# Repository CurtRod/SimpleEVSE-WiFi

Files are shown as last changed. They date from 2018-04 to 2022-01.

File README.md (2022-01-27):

# SimpleEVSE-WiFi

💬 [German version](https://www.evse-wifi.de/dokumentation/)

💾 [Latest Downloads, News and Changelogs (german)](https://www.evse-wifi.de/)

## Attention:
This file describes the structure of EVSE-WiFi in version 1.x.x and is only valid for the ESP8266. For the use of EVSE-WiFi 2.0 (based on ESP32) it is recommended to use the dedicated hardware 'EVSE-WiFi 2.0 Base'. You can find further information on www.evse-wifi.de. The EVSE-WiFi 2.0 Base Module can be bought [here](https://www.evse-wifi.de/produkt/evse-wifi-2-0-base/).

## Introduction

EVSE-WiFi brings WiFi functionality to your EVSE WB/DIN to control your Charging Station very easy. It uses an ESP8266 to communicate with the EVSE WB charging controller via ModBus (UART) and offers a web interface to control nearly everything. Optional there is a possibility to connect an impulse meter via S0 or a Modbus meter (RS485-TTL Adapter is required) and an RFID reader to detect valid RFID tags.

If you want to support this project, I would be very happy about a donation.



## Main Features

* WiFi functionality (as an access point or as a WiFi client)
* Activate and deactivate the Simple EVSE WB via a web interface, RFID tags, API or a button
* 'Always Active' mode - no manual activation necessary
* [HTTP-API](#http-api) to let other devices control EVSE-WiFi
* Setting the charging current via the web interface
* Displays the current charging power in kW (by impulses of a S0 or ModBus meter, optional)
* Displays the charged energy (kWh and km) and the cost of the charge (€)
* User management (RFID tags, optional)
* Log of the last charging processes with output of the charged energy quantity, charging time and costs of the charge (optionally which RFID tag the EVSE was enabled by and the user assigned to it)
* Rudimentary settings (WiFi settings, password for web interface, maximum charging current, etc.)
* Control over all EVSE WB/DIN modbus registers via web interface
* Output of all important parameters of the SimpleEVSE WB (Modbus)
* LED-Support (Pin D0)

## Buy the EVSE-WiFi-Module

If you do not have the time and desire to flash an ESP module and customize the libraries, you can also purchase the already prepared module in the shop with all wires and additional Hardware you need.

[EVSE-WiFi 2.0 Base Module](https://www.evse-wifi.de/produkt/evse-wifi-2-0-base/)

## Preview

Control the Current your EVSE communicates to the vehicle. This page also shows additional data like metered energy and the charging time.

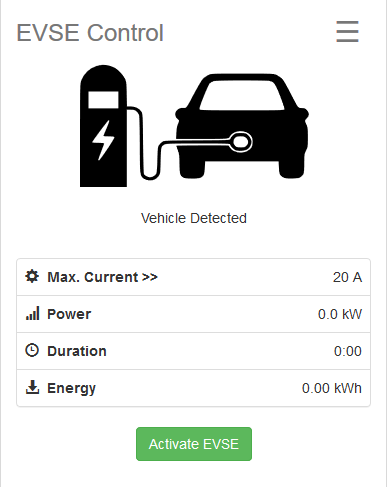
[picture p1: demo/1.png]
Showcase 1

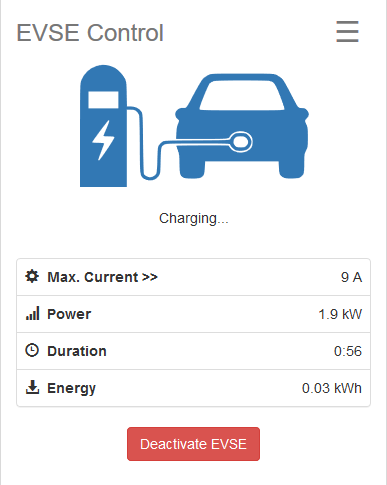
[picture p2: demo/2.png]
Showcase 2


The log page shows the last charging activities.

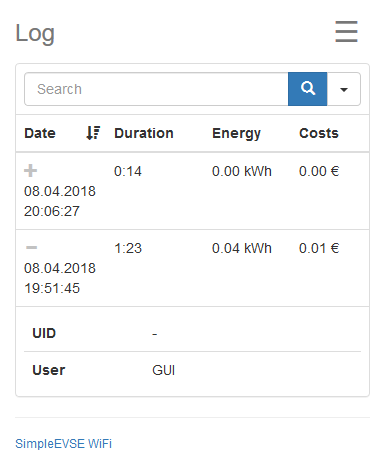
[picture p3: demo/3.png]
Showcase 3


At the users page you can define valid RFID tags that can unlock the EVSE.

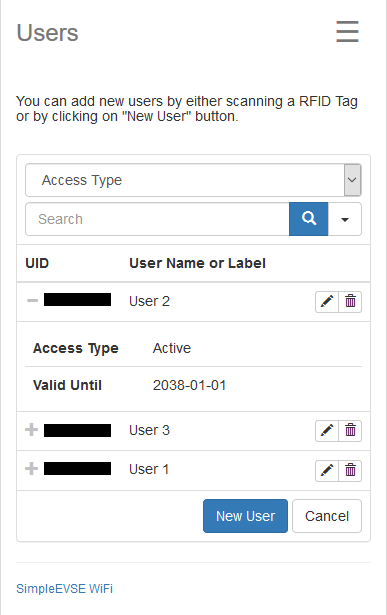
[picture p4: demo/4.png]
Showcase 4


## What You Will Need

### Attention:
This file describes the structure of EVSE-WiFi in version 1.x.x and is only valid for the ESP8266. For the use of EVSE-WiFi 2.0 (based on ESP32) it is recommended to use the dedicated hardware 'EVSE-WiFi 2.0 Base'. You can find further information on www.evse-wifi.de. The EVSE-WiFi 2.0 Base Module can be bought [here](https://www.evse-wifi.de/produkt/evse-wifi-2-0-base/).

### Hardware
* A complete Wallbox based on [EVSE Wallbox](https://www.evse-wifi.de/produkt/evse-wallbox-steuereinheit/) or [EVSE DIN](https://www.evse-wifi.de/produkt/evse-din-ladecontroller/) (min. Software revision 8 (2017-10-31) is needed - read the manual there for updating your EVSE software)
**Attention: revision 9 does not work, because there is a bug in the firmware (sold for a short time in 2018)**
* An ESP8266 module or a development board like **WeMos D1 mini** or **NodeMcu 1.0**
* (optional) An electricity meter with S0 or RS485/Modbus interface. (At this time only SDM120 and SDM630 are supported for use with Modbus)
* (optional) A [RFID Module](https://www.evse-wifi.de/produkt/evse-wifi-rfid-reader-modul/) (PN532 and Wiegand based RFID reader modules are not supported at this time)
* (optional) n quantity of [Mifare Classic 1KB](https://www.evse-wifi.de/produkt/evse-wifi-rfid-karte/) (recommended due to available code base) PICCs (RFID Tags) equivalent to User Number

#### Wiring (WeMos D1 mini/ NodeMcu)
SimpleEVSE-WiFi supports not only the control of the EVSE WB but also the use of a simple button or an RC522 RFID card reader to activate the charging process. With an optional electricity meter, the power requirements of the individual charging processes can be output.

##### Mandatory
This wiring is mandatory and absolutely needed to run SimpleEVSE-WiFi

ESP8266-Pin | ESP8266-GPIO | EVSE WB
----------- | ----------- | -----------
D1 | GPIO5 | TX
D2 | GPIO4 | RX
GND |  | GND

##### Button (optional)
ESP8266-Pin | ESP8266-GPIO | Button
----------- | ----------- | -----------
D4 | GPIO2 | Pin 1
GND | | Pin 2

##### S0 Electicity Meter (optional)*
ESP8266-Pin | ESP8266-GPIO | electricity meter
----------- | ----------- | -----------
D3 | GPIO0 | S0+
GND | | S0-

##### LED (optional)
ESP8266-Pin | ESP8266-GPIO | LED
----------- | ----------- | -----------
D0 | GPIO16 | Anode (+)
GND | | Kathode (-)

##### Modbus Electicity Meter (optional)**
TTL->RS485 | ESP8266-Pin
----------- | -----------
RX | RX 
TX | TX 
VCC | 5V
GND | GND

TTL->RS485 | Modbus Meter 
----------- | -----------
A+ | A
B- | B

##### RC522 RFID-Reader (optional)
ESP8266-Pin | ESP8266-GPIO | RC522
----------- | ----------- | -----------
D5 | GPIO14 | SCK
D6 | GPIO12 | MISO
D7 | GPIO13 | MOSI
D8 | GPIO15 | SDA
GND |  | GND
3.3V |  | 3.3V

Be sure to use a suitable power supply for ESP. At least 500mA is recommended!

\*When you use an electricity meter with S0 interface be sure the S0 interface switches to GND, don't use 3.3V or 5V!

\*\*To use a Modbus electricity meter via RS485, you need a extra piece of hardware to translate UART to RS485. In this project a PCB like [this](https://www.evse-wifi.de/produkt/evse-wifi-ttl-rs485-converter/) is required. Set your meter to baud rate 9600 and slave ID to "002". Until now only SDM120 and SDM630 Modbus meters are supported! If you have another one you can use it with the S0 interface.

#### Preparation of EVSE Wallbox
To use EVSE-WiFi, the modbus functionallity of EVSE WB/DIN is needed! By default, modbus functionality is disabled. To activate it, pull AN input of the EVSE board to GND while booting for at least 5 times within 3 seconds. Modbus register 2001 will be set to 1 (Modbus is active). Attention: That change will not be saved! To save the settings, you have to give a R/W operation at a register >=2000. The easiest way to do this is to activate and deactivate EVSE through the WebUI in the "EVSE Control" page.

### Software

#### Attention:
This file describes the structure of EVSE-WiFi in version 1.x.x and is only valid for the ESP8266. For the use of EVSE-WiFi 2.0 (based on ESP32) it is recommended to use the dedicated hardware 'EVSE-WiFi 2.0 Base'. You can find further information on www.evse-wifi.de. The EVSE-WiFi 2.0 Base Module can be bought [here](https://www.evse-wifi.de/produkt/evse-wifi-2-0-base/).

**Attention:** make sure that the EVSE WB/DIN is not connected to the ESP during the flash process via USB. It could cause overheating of the ESP.

#### Use Compiled Binaries
Compiled firmware binary and flasher tool for Windows PCs are available in on www.evse-wifi.de. On Windows you can use **"flash.bat"**, it will ask you which COM port that ESP is connected and then flashes it. You can use any flashing tool and do the flashing manually if you don't want to use the flash.bat.

[Download Firmware](https://www.evse-wifi.de/download/)

#### Building From Source
Please install Arduino IDE if you didn't already, then add ESP8266 Core on top of it. Additional Library download links are listed below:

* [Arduino IDE](http://www.arduino.cc) - The development IDE
* [ESP8266 Core for Arduino IDE](https://github.com/esp8266/Arduino) - ESP8266 Core
* [ESPAsyncWebServer](https://github.com/me-no-dev/ESPAsyncWebServer) - Asyncrone Web Server with WebSocket Plug-in
* [ESPAsyncTCP](https://github.com/me-no-dev/ESPAsyncTCP) - Mandatory for ESPAsyncWebServer
* [ESPAsyncUDP](https://github.com/me-no-dev/ESPAsyncUDP) - Mandatory for ESPAsyncWebServer
* [ModbusMaster](https://github.com/CurtRod/ModbusMaster) - ModbusMaster Library for communicating with EVSE (**NOTE: Use my Fork of ModbusMaster! Otherwise the wdt reset will be triggered in case of timeout error**)
* [SoftwareSerial](https://github.com/plerup/espsoftwareserial) SoftwareSerial to communicate with EVSE
* [MFRC522](https://github.com/miguelbalboa/rfid) - MFRC522 RFID Hardware Library for Arduino IDE
* [ArduinoJson](https://github.com/bblanchon/ArduinoJson) - JSON Library for Arduino IDE
* [NTPClientLib](https://github.com/gmag11/NtpClient/) - NTP Client Library for Arduino IDE
* [TimeLib](https://github.com/PaulStoffregen/Time) - Mandatory for NTP Client Library
* [ESP8266Ping](https://github.com/dancol90/ESP8266Ping) - Needed for checking online Status

You also need to upload web files to your ESP with ESP8266FS Uploader.

* [ESP8266FS Uploader](https://github.com/esp8266/arduino-esp8266fs-plugin) - Arduino ESP8266 filesystem uploader

Unlisted libraries are part of [ESP8266](https://github.com/esp8266/Arduino) Core for Arduino IDE, so you don't need to download them, but check that at least you have v2.4.0 or above installed.

## First boot
When SimpleEVSE-WiFi starts for the first time it sets up a WiFi access point called 'evse-wifi'. You can connect without a password. To connect, open http://192.168.4.1 in your browser. The initial password is 'adminadmin'. You should first check the Settings to bring the ESP in Client mode and connect it to your local WiFi network. The ESP will be restarted afterwards. If it doesn't restart, press the 'RST' button once. Sometimes the ESP must first be manually reset (this only has to happen after flashing a new firmware).

## Support this Project
The development of SimpleEVSE-WiFi is very time consuming. If you want to support this project, I would be very happy about a [donation](https://www.paypal.com/pools/c/85c7xRbeay).

## HTTP API
Since version 0.2.0 there is an HTTP API implemented to let other devices control your EVSE-WiFi. The API gives you the following possibilities of setting and fetching information.

### getParameters()
gives you the following information of the EVSE WB in json:

Parameter | Description
--------- | -----------
vehicleState | Vehicle state (ready / detected / charging)
evseState | EVSE State (active/not active)
maxCurrent | Maximum Current depending on PP-limit and 
actualCurrent | Actual configured current in A (e.g. 20A)
actualPower | actual power consumption (when S0 meter is used)
duration | charging duration in milliseconds
alwaysActive | Always Active Mode enabled (true/false)
lastActionUser | The user name of the user who performed the last action (activate/deactivate)
lastActionUID | The UID of the user who performed the last action (activate/deactivate)
energy | charged energy of the current charging process in kWh
mileage | charged energy in km
meterReading | actual meter reading in kWh
currentP1 | actual current in A (phase 1)
currentP2 | actual current in A (phase 2)
currentP3 | actual current in A (phase 3)
useMeter | energy meter is configured in EVSE-WiFi (true/false)

#### Example
`GET http://192.168.4.1/getParameters`

> returns JSON like this:

```json
{
  "type": "parameters",
  "list": [{
    "vehicleState": 2,
    "evseState": false,
    "maxCurrent": 32,
    "actualCurrent": 32,
    "actualPower": 5.79,
    "duration": 1821561,
    "alwaysActive": false,
    "lastActionUser": "GUI",
    "lastActionUID": "GUI",
    "energy": 9.52,
    "mileage": 82.3,
    "meterReading": 54.35,
    "currentP1": 8.54,
    "currentP2": 8.54,
    "currentP3": 8.54,
    "useMeter": true
  }]
}
```

### getLog()
returns the following information about the last log entries

Parameter | Description
--------- | -----------
uid | The UID of the RFID tag that was used to activate EVSE
username | The username belongs to the UID
timestamp | Timestamp in seconds since Jan 01 1970 (Unix timestamp)
duration | Duration of the charging process in milliseconds
energy | Charged energy of the charging process in kWh
price | Defined price per kWh in cent

#### Example
`GET http://192.168.4.1/getLog`

> returns JSON like this:

```json
{
  "type": "latestlog",
  "list": [{
    "uid": "ABCD1234",
    "username": "GUI",
    "timestamp": 1523295915,
    "duration": 7504266,
    "energy": 10.32,
    "price": 21
  }, {
    "uid": "-",
    "username": "GUI",
    "timestamp": 1523568920,
    "duration": 1152251,
    "energy": 2.17,
    "price": 23
  }]
}
```

### setCurrent()
using setCurrent() will set the current to the given value (e.g. 18A)

Parameter | Description
--------- | -----------
current | Current to set in EVSE WiFi

#### Example

`GET http://192.168.4.1/setCurrent?current=8`

> Sets the charging current  to 8A and returns

```text
S0_set current to 8A
```
In cases of Error, the answer would be

Answer | Description
--------- | -----------
E0_could not set current - internal error | Internal error occured (unspecified)
E1_could not set current - give a value between *x* and *y*  | Wrong value was given
E2_could not set current - wrong parameter | Wrong parameter was given

### setStatus()
will activate/deactivate EVSE WB

Parameter | Description
--------- | -----------
active | can be true (activate EVSE) or false (deactivate EVSE)

#### Example

`GET http://192.168.4.1/setStatus?active=true`

> Activates EVSE and returns

```text
S0_EVSE successfully activated
```
In cases of Error, the answer would be

Answer | Description
--------- | -----------
E0_could not activate EVSE - internal error | Internal error occured (unspecified)
E0_could not deactivate EVSE - internal error | Internal error occured (unspecified)
E1_could not process - give a valid value (true/false) | Wrong value was given
E2_could not process - wrong parameter | Wrong parameter was given
E3_could not activate EVSE - EVSE already activated! | EVSE is already in state "active"
E3_could not deactivate EVSE - EVSE already deactivated! | EVSE is already in state "deactive"

### doReboot()
reboots EVSE-WiFi via ESP.restart()

Parameter | Description
--------- | -----------
reboot | must be true to reboot EVSE-WiFi

#### Example

`GET http://192.168.4.1/doReboot?reboot=true`

> Returns 

```text
S0_EVSE-WiFi is going to reboot now...
```
In cases of Error, the answer would be

Answer | Description
--------- | -----------
E1_could not do reboot - wrong value | Wrong value was given
E2_could not do reboot - wrong parameter | Wrong parameter was given

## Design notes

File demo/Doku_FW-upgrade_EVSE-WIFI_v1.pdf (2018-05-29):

Dokumentation für das Aufspielen einer neuen „EVSE-WIFI“ Firmware auf einen ESP8266 – Stand 24.05.2018
Anleitung für Windows-PC
1. Aufruf der „EVSE-WIFI“-Webseite im Browser: Adresse http://192.168.xxx.yyy (IP-Adresse entsprechend aktuellem Modus (client- oder AP) wähen)
2. Login mit PW und zur setting-Seite navigieren

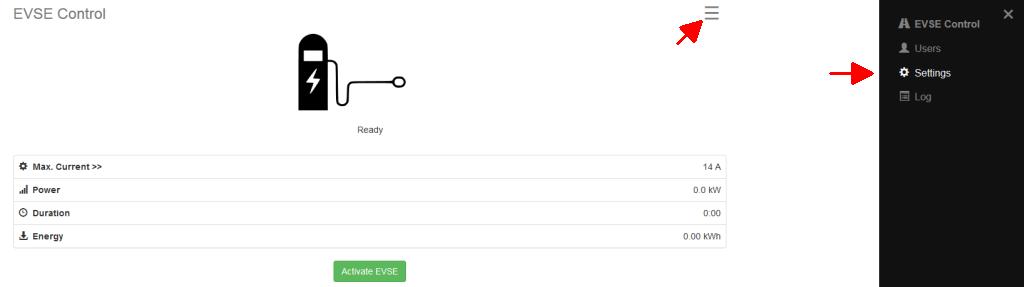
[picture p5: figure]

3. An das untere Seitenende scrollen, nun Daten (a) und Settings (b) in jeweils eine Datei sichern
Anschließend dem link „latest version“ (c) folgen

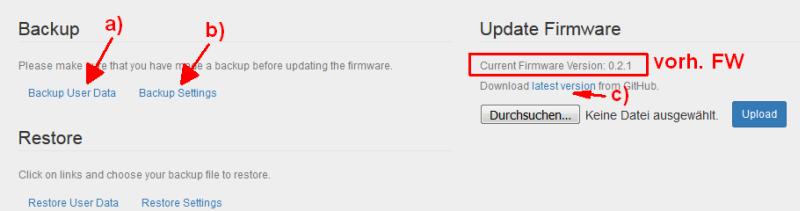
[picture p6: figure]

4. auf Github in das aktuelle EVSE-WIFI-Versionsverzeichnis (hier 0.2.2) navigieren und die Datei Source code.zip in ein PC-Verzeichnis Deiner Wahl downloaden (meist in den Download-Ordner)

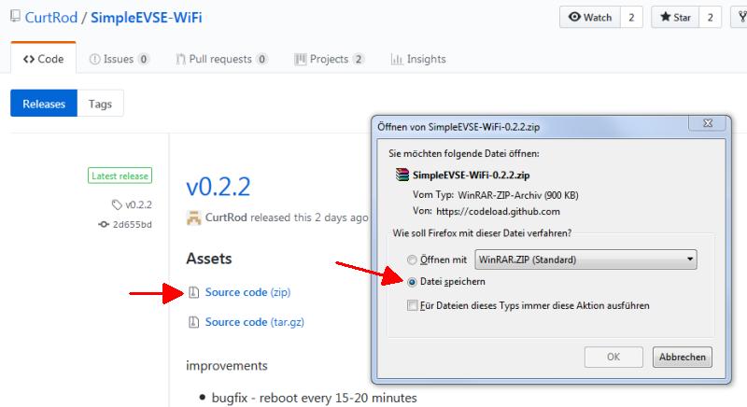
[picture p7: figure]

5. zip-Datei auf dem PC entpacken => In etwa folgender Inhalt muss erscheinen.

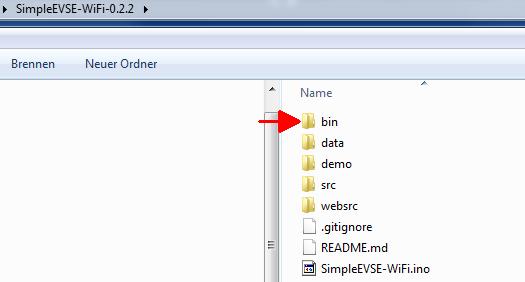
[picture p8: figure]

6. Nun mit Explorer in den Ordner bin u. ggf. Unterordner (hier latest) wechseln und das Vorhandensein der Datei built.bin prüfen

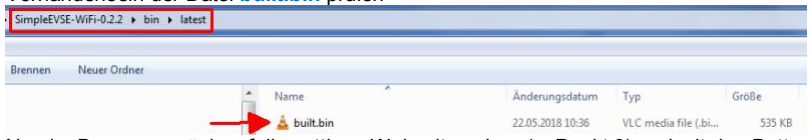
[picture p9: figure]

7. Nun im Browser zurück auf die settings-Webseite gehen (s. Punkt 3) und mit den Button „Durchsuchen…“ (d) zu lokal gespeicherten built.bin-Datei navigieren,
nach Doppelclick auf built.bin (oder Öffnen) ist die neue Firmware für den upload bereit (e), nun den Upload-button starten (f)

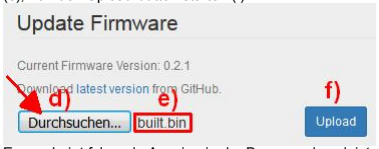
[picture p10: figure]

8. Es erscheint folgende Anzeige in der Browseradressleiste:
9. Nach ca. 30s warten, bitte die IP von „EVSE-WIFI“ aufrufen (s. Punkt 1) und wieder zur setting-Seite navigieren (s. Punkt 2) => dort die neue FW-Version prüfen

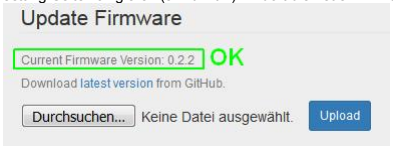
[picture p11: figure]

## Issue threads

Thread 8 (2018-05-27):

Save & Reboot doesn't work

Leftaf, 2018-05-27:
In the build 0.2.2 the [Save & Reboot] button is complain the the default PW is shorter than 8 Char, but if I change it and also other settings it doesn't save them to the config file.

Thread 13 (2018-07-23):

SimpleESVE - Firmware Version

njordan77, 2018-07-23:
Sorry to post this in issues as this is no issue at all, but no other chance seen to get in touch with the developer. Is there any chance/hidden website that would provide firmware version of the controller board. I bought it recently but would like to see if its rather up to date or better should buy a Pickit3/4....Thanks Norbert

njordan77, 2018-07-23:
ah, sorry - just did dig deeper - there is a device status part where one register names the firmware version. Says 9, which seems to be the latest one on the internet dated 180425. Regards

Closed 2018-07-23.

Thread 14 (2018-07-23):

Button yes/no?

njordan77, 2018-07-23:
One short question before i add this element. What if i do not consider a button? will it start when plugged in or it waits until the GUI activates the controller?

What if i use the button and activate and somebody else presses the button again....will it disable again? if this is the case its a little dangerous if i leave the car in public and e.g. kids playing next to this nice box and turn it off "accidentially"....

Thanks a lot for clarification, Norbert

CurtRod, 2018-07-23:
Hi Norbert,

Thank you for your Message! SimpleEVSE-WiFi waits to activate until the button is pushed, reading a RFID tag or activating via WebUI.
Deactivating works the same. So yes, it could be dangerous, when kids playing next to the Box! ;-)
A possible solution could be a flag in the Settings like "allow deactivating via Button". Maybe this will be delivered with the next release.

You can follow the discussions about SimpleEVSE-WiFi also on goingelectric.de (german):
https://www.goingelectric.de/forum/ladeequipment/simpleevse-wb-mit-wlan-t31260.html

Curt

njordan77, 2018-07-25:
One question regarding the hardware part of this button.
Should the button bring GND to the configured GPIO pin? should this be done simply via connecting to GND....or should this be done via PULL-UP Resistor in combination with the button in order to have stable 3,3V when not pressed at the pin.

How about debounce, is there something implemented in Software or its expected to happen in Hardware? Regards Norbert

CurtRod, 2018-07-26:
Hi Norbert,
as described in README.MD the button should bring the GPIO to GND. The ESP8266 Module has internal Pull-Up resistors, which are used here. There is no hardware Pull-Up necessary.
Debounce is already prevented in Software.

Curt

Macrisu, 2019-07-23:
The original design asks for an auto-reset button.
I used that button with ESVE-Wifi and it works only if the connection is closed (I keep pressing the button).
It can be made to work with that button, or do I need to buy a classic on/off button?

Closed 2018-07-23.

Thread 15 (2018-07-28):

No authentication possible on Safari MacOS and iOS

michel72, 2018-07-28:
It's not possible to authenticate on iOS and MacOS because apple devices do not allow basic auth without https.

In short, it's not possible to use the webUI from and Apple IOS device at all and It's not possible to use the webUI on a Apple Macbook using the Safari webbrowser. It does work on a Macbook when using Chrome or Firefox.

njordan77, 2018-08-01:
can confirm this....on Win10 everything connects perfect to APmode....but iphone does show the login mask but from there it does not continue with correct password into the main GUI.....is there a way to fix this?

njordan77, 2018-08-14:
Any progress here, or solution that could fix the issue?

CurtRod, 2018-08-14:
Sorry for late response. I will try to find a solution asap.

Leftaf, 2018-08-28:
I found following https://github.com/Links2004/arduinoWebSockets

and Issue https://github.com/Links2004/arduinoWebSockets/issues/25

may this help to improve security to iOS

njordan77, 2018-11-11:
Hi, any update? Tried recently the latest version + hoped naively that IOS12 could have fixed it - but no success. Still not able to connect in AP Mode from my Iphone. Connecting with my PC (Win+Firefox) is no problem at all. Regards Norbert

CurtRod, 2018-12-25:
I suspect the error in the JS part of the web interface. Unfortunately, I do not have a Mac to hit the debugger in Safari. So at the moment I can not analyze what exactly the problem is. Does anyone have the opportunity to do this? That would be great.

njordan77, 2018-12-25:
hi, i would love to support - but the only thing i have in hand is an iphone 6s - if that may help. Thanks for the support!

michel72, 2018-12-26:
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

michel72, 2018-12-26:
Safari does not allow basic auth for websockets.

https://serverfault.com/questions/910702/apache2-safari-exclude-basic-authentication-for-websockets

michel72, 2018-12-27:
@CurtRod , if you need any help testing, I have an iMac, macbook, iPhone and iPad available.

CurtRod, 2018-12-27:
@michel72 , thank you. I wondered, because i've seen some other projects using websockets with basic auth and there are no problems with safari. I have only an iPhone 7 for testing here but there is no way to debug with that.
**good news for all Apple users:**
In the next release will be an option to deactivate the basic auth, however this should only be a work around and not a preferred solution.

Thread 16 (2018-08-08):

Feature request: Options to autoactivate the charging station on power on and to prevent deactivation after charging

FrenkK, 2018-08-08:
Hello :) First of all, thank you for this very useful project, it fills a real need!
I'm using it on my home charging station for three primary purposes: for monitoring, to be able to dynamically adjust charging amperage to prevent my main fuses from blowing out (using the setCurrent API) and for the power measurement capability. Configuration: a S0 energy meter, no RFID, no button.
I have two issues:
1. Currently, the controller will turn off the SimpleEVSE after each charge (writing 8192 to register 2005 at the start). This is a problem on my Ampera for two reasons:
  - The car stops indicating a full charge and I can't verify a proper charge without turning the car back on. We have very unstable power, so charging problems happen more often than you would think.
  - Ampera should be always connected to a charger in extremely warm or freezing weather so the system can protect the battery by heating or cooling it (AFAIK, this goes for other e-cars as well).
2. There are several of us using this station and everybody expects to just plug in the cable and leave. If a  short blackout occurs (and it does quite frequently), the station restarts, but does not reactivate, so they have to first check if it is charging and then activate it, if it doesn't, This already caused some failed charges.

I think these issues will probably be bothering other people as well, so it would be nice to have two simple checkboxes in config: "Do not deactivate after finished charge" and "Automatically activate the station on power on".

Leftaf, 2018-08-10:
Hi Frenkk,

For the handling with the Cars there is a possibility to improve. If you have a cable with Plug normally PP is fix with GND connected e.g. 680 ohm to indicate 16A . If you modify the Plug to that the PP to GND can be opened. The Car would normally get reactivated and will try to charge again.

To avoid blackouts on the esp6288 side you may use the latest version with battery support. [WEMOS V2.0.0](https://wiki.wemos.cc/products:d1:d1_mini_pro)

CurtRod, 2018-08-28:
@FrenkK Thank you for that feature request. I have already considered that this may be a possible scenario. Via hardware it will probably not be possible to stop setting register 2005. Each time the ESP is restarted, EVSE WB is automatically deactivated.
The problem with the implementation right now is that it's not so easy to notice that a charge has been started. This would require the EVSE WB to be polled for every few seconds. But it's not impossible. I'll include that in the backlog as a new feature. At the moment, however, there is still a stability issue with the HTTP API, which should be fixed before. I keep that in focus.

FrenkK, 2018-09-02:
Thank you for keeping this in mind. I actually bodged up a quick fix to prevent the autodeactivate on startup and recompiled, but it is not even close to a proper solution.

ronmichel, 2019-10-06:
@FrenkK Could you be so kind and share your quick fix to prevent the autodeactivate on startup? Thanks so much!

FrenkK, 2019-10-08:
@ronmichel What I did was to strip all the code I don't need from the 2.6 version and then add the logic that keeps it on. There is also a tweak to the JSON reporting of current, I removed the unnecessary nesting in the result that was messing with my Home Assistant setup.
You are free to use the slimmed down code attached, but it's a quick and dirty job with some functions (like Modbus meter support) removed.
[SimpleEVSE-WiFi.zip](https://github.com/CurtRod/SimpleEVSE-WiFi/files/3700710/SimpleEVSE-WiFi.zip)

ronmichel, 2019-10-08:
Thanks! I also plan to use it with HA so it suits just fine!

CurtRod, 2019-12-03:
resolved with version 0.3.0

Closed 2019-12-03.

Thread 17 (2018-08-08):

Contribution: STL files for a simple 3D-printed DIN-rail enclosure for the WeMOS D1 mini

FrenkK, 2018-08-08:
I made a simple DIN-rail enclosure design for the WeMOS D1 mini.
It's made of two halves that are screwed together using recessed-head wood screws. There is (just) enough space to install a simple 5V power supply cannibalised from a phone charger. The antenna is exposed for best possible WiFi reception.
Build:
1. For safety, print using fire retardant plastic.
2. Connect all parts and use a drop of superglue to hold them in place in the enclosure.
3. Screw the enclosure together using 4x 3,6x16 mm wood screws with a recessed head.

See the picture for the final look (rightmost module).
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
[STLs.zip](https://github.com/CurtRod/SimpleEVSE-WiFi/files/2269021/STLs.zip)

Macrisu, 2019-08-15:
Thank you for the 3D STL files.
I see that you also put a LED and button on the DIN case, very nice.
You use the button to activate the charge?

I've tried this, but it does not seem to work for me. I have an auto-reset button that works only if I keep the button pressed manually.
**Your button is on/off or auto-reset?**

Thank you

FrenkK, 2019-08-16:
> You use the button to activate the charge?
No, this is a fallback in case the SimpleEVSE-WiFi fails. It is a momentary NO switch corrected directly to the control input on the Simple EVSE Wallbox. If there is ever a big problem with the Simple EVSE Wifi, I can just turn off its power and use the wallbox on it's own.

Macrisu, 2019-08-16:
Do you have the original cad files for STL?
I want to make the WeMOS D1 mini support smaller.

FrenkK, 2019-08-17:
Sure, I added them to the original post.

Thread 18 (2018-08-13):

switch to STA mode is failing only emergency AP Mode get's activate.

Leftaf, 2018-08-13:
It looks like that there is an issue to switch from AP mode to STA after once AP has been Setup successful.

Trying to go into STA mode always the WEMOS start in fallbacktoAPMode();
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
as this function is only called in the Setup(); sequence there must be an issue with loading the config.json
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

Does any body else have this behavior?

in depend of this behavior the [debug] activation is unfortunately after the relevant error messages :-( so the code should be move upwards and the first messages should be always shown.
`````
bool ICACHE_FLASH_ATTR loadConfiguration() {
  File configFile = SPIFFS.open("/config.json", "r");
  if (!configFile) {
    Serial.println(F("[ WARN ] Failed to open config file"));
    return false;
  }
  size_t size = configFile.size();
  std::unique_ptr<char[]> buf(new char[size]);
  configFile.readBytes(buf.get(), size);
  DynamicJsonBuffer jsonBuffer14;
  JsonObject& json = jsonBuffer14.parseObject(buf.get());

  if (!json.success()) {
    Serial.println(F("[ WARN ] Failed to parse config file"));
    return false;
  }
  if (json.containsKey("debug")){
    debug = json["debug"];
  }
  if(debug){
    Serial.println("Debug Mode: ON!");
    Serial.println(F("[ INFO ] Config file found"));
    json.prettyPrintTo(Serial);
    Serial.println();
  }
  else{
    Serial.println("Debug Mode: OFF!");
  }
```

CurtRod, 2018-08-14:
Thank you for reporting this issue. I will have a look at this in the next days!

CurtRod, 2018-08-28:
okay. I changed the lines a bit diffent, but now there would be an error message on Serial, when no config file is found. Thank you for your help.

Closed 2018-08-28.

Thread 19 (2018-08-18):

Dangerous: EVSE defaults to 32A after reboot!

michel72, 2018-08-18:
I have noticed the SimpleEVSE-Wifi defaults to 32A after a reboot even though I have set the MAX CURRENT in settings to 20A. THe webUI shows 32A and that settings is actually active.
This leads to a potential dangerous situation as the car will pull 32A if activated after a power failure.

I have set the ESP to
- Wifi client
- Meter hardware to SO
- NO RFID
- MAX Current: 20A
- NO button
- NTP server set to pool.ntp.org
- time zone set to GMT+1 Brussels

EVSE Registers
1000: Configured Current	16
1001: Actual Current	16
1002: Vehicle Status	3
1003: PP-Limit	20
1004: Turn off bit	0
1005: Firmware Version	9
1006: EVSE Status	2
2000: Current after boot	32
2001: Modbus Status	1
2002: Min. Current Value	5
2003: Analog Input Config	1
2004: Amps after boot (evse-button)	0
2005: Register 2005	8192
2006: Current Sharing Mode	0
2007: PP-Detection	0

Current after boot is set to 32A, but I have no clue as how to set that to 20A.

Leftaf, 2018-08-23:
In depended of this situation. My understanding is that the resistance PP-PE will overrule physical the limit

If you have bluetooth available try the APP from the developer to change the register.
http://evracing.cz/evse/evse-wallbox/app_20171118.apk

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

CurtRod, 2018-08-23:
Hi michel72,

sorry for the late response. You don't need the HC06 BT Interface to do that. In the WebUI of SimpleEVSE-WiFi you can click the 'pencil' on top of the table 'EVSE Registers' in Settings page (see attached screenshots). Click that and than you can change register 2000 (Current after boot) to 20.
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

Curt

michel72, 2018-08-23:
Ahh thanks. This was obviously not a bug :)

Closed 2018-08-23.

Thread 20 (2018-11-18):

Reconnect or connect if use timer

autodiag, 2018-11-18:
I have a bit of a problem with using in a while when I have a timer setting (to run at a low tariff) so the charging is not started, is the problem of the system itself or is the problem elsewhere?
if it's a system problem, would it be good to run timers and run automatically at the set time?

the kind of problem is that if I press the button on the car connector, I will not be charged as I have any other chargers and I have to re-enter the phone (or the button)
I have a 680R resistor (for 20A limit) PP to GND ..
Is this involved well or do I have to engage PPs on the car?
it was not quite clear to me from the description

Martin

autodiag, 2018-11-18:
i use J1772 and car is Fiat 500e

CurtRod, 2018-12-25:
Hey Martin,

sorry for the late reply, I was a little longer on vacation. :)
The 680R resistor in the cable should not be a problem.
Do I understand correctly that you are using the timer function of your vehicle? There will be a timer function directly in SimpleEVSE-WiFi with one of the next releases. Maybe that would be the easier way. Is SimpleEVSE-WiFi in the status 'activated' when the vehicle requests the charging depending on the vehicle's pre-setting?

Curt

autodiag, 2019-01-17:
when I have a timer set in my car due to a cheap night's charge, the EVSE does not charge the car, it will not start ... just start if the timer is off, I load the charger and charge ... but if I pull out the charger and reinsertion or if the electrified site will drop out of the car and it will not restart again .. it will be possible to run the manual manually via the web interface ... it might not be wrong to choose whether to plug in the car or to start up manually, that would solve the problem, I think along with the timer to help the charger, not the car

Matin

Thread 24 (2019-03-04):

Feature Request: stop charging when power/current below defined value (stop charging at 80%)

badsoden, 2019-03-04:
It would be nice if one could set a treshhold where the charging will be halted when power/current gets below defined value. The idea is to set that value where the SoC is about 80%. Not all cars support charging stop at a certain SoC value and this way the EVSE could manage this. It increases lifetime of the battery and allow full recuperation right after start driving. E.g. Renault ZOE does not have an option to charge at 80% and the battery must be well below ca. 90% to have full recuperation. So charging at 80% is good for battery and lowers your average consumption.
For each car the owner shuld first estimate/assess the actual current at 80% SoC and then set the treshold accordingly.

FrenkK, 2019-03-04:
AFAIK, the car does not send a feedback about state of charge to the EVSE with SAE J1772 signaling protocol, so this is not really feasible without some additional hardware, at least not accurately.
The recuperation is a valid argument, but that aside, I question if it makes sense to do this. Car batteries are used in a much narrower voltage window than consumer batteries you can find e.g. in phones. In my Opel Ampera, for example, only 10 out of 16 kWh capacity is used and cell voltage never goes above 4 V (as opposed to 4,2 V in consumer batteries). Decreasing the charge window still further will probably not make much difference and you should already get at least some 5000 cycles of life. It may be a factor with some cars, depending on their use of the battery, although for sure not a big one.

badsoden, 2019-03-04:
I though so, that there is no feedback about SoC. That's why I suggested to use the charging curve. The car reduces charging current at around 70 to 80% with most cares and I though I use that to estimate SoC. I thought in its most simple form one would just be able to set minimum current and when it goes below charging stops. It most have a short waiting time before it kicks in to ensure the car takes maximum power (above the treshhold). E.g. logic would be: after start charging wait one minute and then if current below xyz then stop.
That 80% is better for the battery I derived from Tesla that normally stops at 80% unless you explicitly set the flag to charge 100%. That some manufacturers put more capacity in the car than actually seen is true. In my ZOE I though it is another 2 or 4 KWH on top of the specified 22 KW.

Recuperation is especially valid if one lives uphill. If you charge till 100% and drive down after charging then that last 5% to 10% of charge is basically wasted because one can't recuperate.

FrenkK, 2019-03-04:
Yes, the charging curve approach should work, if you have an energy meter connected. It is not trivial, though, because it must take into account the set current that can change with dynamic load shedding, for instance.

badsoden, 2019-03-04:
That is very true, one probably has to average out the (s0) measured values over some minutes and then shut off charging. If one loads 79 or 81% is not very critical anyway so a few minutes earler or later is not important. Some basic rolling robin algorithm should do the job.

Macrisu, 2019-07-20:
for LEaf, It can be done with an Android APP.
https://play.google.com/store/apps/details?id=com.chk.lcc&hl=en

premultiply, 2019-11-22:
The way to estimate the SOC from the charging power does not work reliable.
Charging Power measured on EVSE side depends on many factors like battery temperature, pilot signal, battery voltage, preconditioning state, battery heating, ...

It would end in may problems and failures.

Apart from that it is kind of useless as the BMS keeps track of the battery health itself and 100% displayed SOC for user does not mean the battery cells are fully charged on most types of cars, especially ZOE.

badsoden, 2019-11-22:
I know the ZOE doesn't report real SoC. My main issue is, that recuperation is more or less disabled when you start driving with a 100% battery. In fact I don't mind when the battery is loaded somewhere between 75 and 95 %. I just want to sty away from the 100%. I also not so convinced that Renault's BMS is very accurate with loading. Renault is quite buggy with all of their SW hence why would their BMS be an exemption. So, if unreliable means one day (e.g. when cold) it would stop at 75% and another day in summer it would charge to 90% I can live with that, recuperation will work right from start and the battery will definitely not suffer from that. Actual current measurements can come from S0 sensor or RS485 bus from separate power meter.
Is it worth it to make this effort on the EVSE for a ZOE only? Not sure obviously and not up to me to judge or answer. ZOE is a popular car but if it is the only EV with such limited charging control then I understand it's low on the priority list. I really don't know how many cars do not allow to set the end of charging at a certain level of SoC. The facelifted ZOE (2019) doesn't allow it either. Their App to track charging or SoC is not working any more which I found all quite disappointing. One could overcome it by setting a timer but this is quite cumbersome as one can set a clock but not a timer.  The environmental gain of a EV does depend on the final life span of the battery and ZOE is not really making an effort here it seems.

premultiply, 2019-11-23:
Why dont you have a look for OpenWB? All these kind of advanced features are included there.

But this project here should hopefully stay smart, small and clean.

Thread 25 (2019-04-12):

MQTT for EVSE-WIFI

roesl, 2019-04-12:
Is it possible to add MQTT feature to Control the EVSA wit MQTT commands ?

Georg

s0170071, 2019-09-16:
+1 from me.
I do already have the mains power readings and solar power readings in my OpenHab installation.
I would like either
a) communicate these power readings to EVSE so it can use it for solar charging
b) control power output of EVSE myself (based on my readings)
MQTT style is very much appreachiated.

neographikal, 2020-02-16:
+1

This would make it much more versatile!

alx2k, 2020-02-25:
@neographikal, It would be much more versatile, but it is not needed.

I have "home assistant" at home, and a wemosEM power meter (also on github). When my home consumption changes in 1 Amp, home assistant sends a http request to the charger using "http://192.168.4.1/setCurrent?current=XXXX". It works flawlessly.

@s0170071, If you want, I can send you my home assistant configuration, maybe it is similar in Openhab.

neographikal, 2020-02-25:
I can get it to work, but MQTT is much more versatile, reliable and almost everything I use is connected through MQTT. Especially when it's a ESP32/8266 (Tasmota/esphomelib), for some stuff I even wrapped the existing API for MQTT with Nodered.

Thanks for the suggestion but this still would be important to me :)

spoeh-man, 2020-05-11:
+1 for me is also better with mqtt for iobroker

njordan77, 2020-05-13:
i would also love to see your great project compatible with MQTT (pubsubclient, rather easy to handle)

kolaCZek, 2020-06-24:
+1 Do want!!!

krispek, 2020-07-07:
+1 for me. The HA-solution works, but MQTT would make it even better. :)

captain186, 2020-10-15:
> If you want, I can send you my home assistant configuration, maybe it is similar in Openhab.

Hi, I'm intrested in using evse-with home assistant. Could you send me your configuration, please?
Thanks a lot in advance!

kolaCZek, 2020-12-01:
```
rest_command:
  evse_enable:
    url: 'http://192.168.0.140/setCurrent?current=13'
  evse_disable:
    url: 'http://192.168.0.140/setCurrent?current=0'

switch:
  - platform: template
    switches:
      wifi_evse:
        value_template: "{{ is_state('sensor.wifi_evse', '13') }}"
        turn_on:
          service: rest_command.evse_enable
        turn_off:
          service: rest_command.evse_disable
```

alx2k, 2020-12-01:
Sorry for the delay, I did not see Github notifications. My code changes the current depending on the main house energy meter consumption (working with a WemosEM).

It reads the house energy consumption on the meter, and sustracts that consumption from my contract maximum amperage (34 Amps), so I don't get any energy cuts due to amperage overlimit.

Code is:
`rest_command:
    simpleevsewifi:
        url: http://192.168.1.40/setCurrent?current={{ states('sensor.Amperios_Cargador') }}

sensor:
  - platform: mqtt
    state_topic: "wemos/wemosEM-4568CC/power"
    name: Amperios Cargador
    icon: mdi:power-plug
    unit_of_measurement: "A"
    value_template: "{% if 34 - value_json.current | round(0) > 32 %}
    {{32 | round ()}}
    {% else %}
    {{34 - value_json.current | round(0)}}
    {% endif %}"
`

captain186, 2020-12-07:
Thanks a lot! I'll try it out!

riogrande75, 2020-12-31:
+1

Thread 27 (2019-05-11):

Metering just doesn't work

fsg4u, 2019-05-11:
Hey,
Great project and the charging worked nearly out of the box but it just can't neater the Power with the S0 counter.
It stays at 0.00kW the whole time.
I checked the S0 pins and it drags 3.3V down to 0V every 0.5Wh and the pulse is supposed to be 80ms.
Any Idea what could be wrong?
Thx

twityde, 2019-05-24:
Did you check the polarity?
It is important how you connect the S0.
S0+ to GND, S0- to D3/GPIO1.

fsg4u, 2019-05-24:
Hey, Yes I did. Didn‘ work either but I just changed the GPIO and now it’s working. Perhaps it’s just that the GPIO is broken

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

hgmendes, 2019-08-26:
I'm having this problem now.
S0+ connected to D3 and S0- to GND, but stays at 0.00 kWh.

Meter doesn't inform impulse lenght, but I've tried with 80 and 60ms.

Anyone has this working with an Orno OR-WE-507 meter?

CurtRod, 2019-08-30:
Did you try to change the polarity?
Many other Orno electricity meters have a pulse length of 90ms. For the OR-WE-507 I could find no exact information. If necessary, ask the manufacturer directly.

hgmendes, 2019-09-02:
Hi,

Thank you for your reply.
I've already asked manufacturer but until now theres no answer :/

Regards,

Hugo Mendes
GSM PT: +351 916 903 578
Skype: hgmendes

CurtRod <notifications@github.com> escreveu no dia sábado, 31/08/2019 à(s)
00:24:

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

hgmendes, 2019-09-10:
Solved! Works ok with 90ms pulse! Thank you!

Closed 2019-11-22.

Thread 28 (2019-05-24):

HTTP API: getParameters returns wrong values

twityde, 2019-05-24:
I integrated Simple EVSE to my SmartHome System.
If in unconect the car or stop loading, getParameter returns still the wrong State.
After Login to the Simple EVSE UI the values will be correct.

Here are sample Data from my last charge 2 Days a go. Copied five minutes ago:
{"type":"parameters","list":[{"vehicleState":3,"evseState":false,"actualCurrent":20,"actualPower":0,"duration":1013998861,"energy":5.28,"mileage":35.2,"meterReading":14.91,"currentP1":0,"currentP2":0,"currentP3":0}]}

After login to the UI:
{"type":"parameters","list":[{"vehicleState":1,"evseState":false,"actualCurrent":20,"actualPower":0,"duration":0,"energy":0,"mileage":0,"meterReading":9.63,"currentP1":0,"currentP2":0,"currentP3":0}]}

And the log entry will be also wrong:
{"type":"latestlog","list":[{"uid":"","username":"","timestamp":1558286890,"duration":3653892,"energy":4.39,"price":27},{"uid":"","username":"","timestamp":1558290917,"duration":1014021464,"energy":5.28,"price":27}]}

andig, 2019-06-05:
in

    server.on("/getParameters", HTTP_GET, [](AsyncWebServerRequest * request) {

we have

    item["vehicleState"] = evseStatus;

and in

    bool ICACHE_FLASH_ATTR queryEVSE() {

there is a lot of updating `evseStatus`.

However I'm not sure that `evseStatus` is really updated in every codepath.

twityde, 2019-06-05:
In the menatime i checked the log file of my home assistant server.
If i deactivate the wallbox by API, the esp returns "S0_EVSE successfully deactivated".
For me it looks like queryEVSE(); in deactivateEVSE(true); does not work correctly. Maybe a sleep will help.

Can somebody try to reproduce this bug?

Steps to reproduce:
1. Connect car to SimpleEVSE
2. Activate EVSE by using the HTTP API
3. getParameters by using the HTTP API
4. Deactive EVSE by using the HTTP API
5. Get Parameters by using the HTTP API
6. Login to Web UI
7. Get Parameters by using the HTTP API

andig, 2019-06-05:
Might help to post the api results after each step? Also: does it make a difference if you deactivate by api or the car stops charging?

twityde, 2019-06-05:
@andig  i tried it just now. If the car stops the charging, everything is correct.
But it is reproducable everytime i stop via api.

andig, 2019-06-05:
Could you share the api results up to where there‘s a difference? Is the root cause the api to stop or the missing ui login? Serms the stop api is the actual problem?

It might make sense to log the actual evse api output- maybe the root cause is in the evse firmware instead of here?

twityde, 2019-06-05:
The getParameters returns:
{"type":"parameters","list":[{"vehicleState":1,"evseState":false,"actualCurrent":20,"actualPower":0,"duration":0,"energy":0,"mileage":0,"meterReading":0,"currentP1":0,"currentP2":0,"currentP3":0}]}
After the car stopped the charging.

Deactivating by API returns "S0_EVSE successfully deactivated".
```c
      else if(strcmp(awp->value().c_str(), "false") == 0){
        if(evseActive){
          if(deactivateEVSE(true)){
            request->send(200, "text/plain", "S0_EVSE successfully deactivated");
          }
          else{
            request->send(200, "text/plain", "E0_could not deactivate EVSE - internal error!");
          }
        }
        else{
          request->send(200, "text/plain", "E3_could not deactivate EVSE - EVSE already deactivated!");
        }
      }
```
So deactivateEVSE(true) returns true.
But in deactivateEVSE the result of queryEVSE() is not used.

I will try to attach a serial monitor and check the output.

twityde, 2019-06-05:
Strange. With Putty attached it works like expected:
```
true
[ ModBus ] Query Modbus before activating EVSE
[ ModBus ] got EVSE data successfully
[ ModBus ] EVSE successfully activated
[ ModBus ] got EVSE data successfully
[ ModBus ] got EVSE data successfully
[ ModBus ] got EVSE data successfully
[ ModBus ] got EVSE data successfully
[ ModBus ] got EVSE data successfully
[ ModBus ] got EVSE data successfully
false
[ ModBus ] EVSE successfully deactivated
[ ModBus ] got EVSE data successfully
```

andig, 2019-06-09:
> It works, but i don't like it.

Its ugly because now the call becomes synchronous.

`queryEVSE` is always called from the main loop and `getParameters` will just use the latest value. You could add more logging to see if the query is called from the main loop _after_ you have deactivated. I'd also suggest to add logging of the raw register values in `queryEVSE` in case the output from the EVSE is different in both cases.

andig, 2019-06-09:
Actually, if you look here https://github.com/CurtRod/SimpleEVSE-WiFi/blob/master/SimpleEVSE-WiFi.ino#L1814 it seems if it won't be queries if `evseActive=false`- might this be the problem?

twityde, 2019-06-09:
I will change line 1814 and remove the condition evse Active.

But the question is, why does the queryEVSE in the deactivate function doesn't work?

Could it be that simple evse deactivate asynchronous?

andig, 2019-06-09:
I‘m only guessing. Maybe it takes a moment on the evse side?

rtfmjoey, 2019-11-21:
I'm integrating with Domoticz and am running into the same issue. I noticed that when I have the EVSE web page open somewhere and then use the API everything works ok.

When I don't have the webpage open it takes somehwere from 5 to 60 seconds before anything happens and occasionally nothing happens at all...

CurtRod, 2019-11-22:
with update to 0.2.8 the issue is resolved

Closed 2019-11-22.

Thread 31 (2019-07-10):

ESP8266-Pin vs ESP8266-GPIO

Macrisu, 2019-07-10:
What's the difference between ESP8266-Pin and ESP8266-GPIO?

I see that one is using GND, the other not.

Simaho99, 2019-07-18:
Hello! the PINout numbers on ESP 8266 do not corresponds to the GPO numbers, I had the same problem recently, Use the GPO numbering in the development, it works.
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

Closed 2019-11-22.

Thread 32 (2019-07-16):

Charge won't start

hgmendes, 2019-07-16:
When i press 'Activate EVSE' it won't start charging, 'Deactivate EVSE' turns green after some seconds. I could hear contactor closing and opening in a few seconds interval. Reseting all parameters to default (with no SimpleEVSE-Wifi) charger is working fine.

Macrisu, 2019-07-16:
Plz give details on full setup.
Some pictures with the setup can help.

Are some registers modified from default?

hgmendes, 2019-07-16:
Hi, thank you for your reply.

I don't have pics right now, but I could send tomorrow.

I have already tried in several SimpleEVSE WB and also in a SimpleEVSE Din.
Setup is only SimpleEVSE (firmware 11) and Webos D1 Mini. D1 and D2 to
TX/RX, 5V and ground to VCC and ground on SimpleEVSE. All parameters in
default.

Regards,

Hugo Mendes
M: +351 916 903 578

A terça, 16/07/2019, 23:52, Macrisu <notifications@github.com> escreveu:

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

Macrisu, 2019-07-17:
My EVSE Din is still on the post so I'll try your pain soon.
I'm working with NodeMcu, as I hate to solder pins.

=====
NOTE#1: By default, MODBUS is NOT enabled, so the original analogue input switches can
be used (current limit and current boost functions). MODBUS can be enabled by pulling
AN input down to GND while booting (= when you power the device up) at least 5 times
within 3 seconds (button activated). This will change register 2001 to the value 1,
but it will not save the value permanently. _The value will be saved after the first successful R/W
operation over MODBUS (register number >=2000)_.
=====

**Are you sure that Modbus is enabled permanently?**

1. Verify if your PINS are soldered correctly on Webos D1 Mini.
2.
D1-TX
D2-RX

This can be mixed by mistake!

2. The documentation for EVSE is a mess, as many have changed over different version of FW + DIN version has si own pinouts.
Also, the new HW has Mobus active by default, but you should try to verify the default registers, as I suspect that there is the main problem.

For my setup (kW, WIFI and RFID and Type 2 soket), I plan to check the Registers:
2000 - 32
2001 - 1
2003 - 0
2004 - 0
2005 - b0-0, b1-0, (I do not plan to use the button)
2007 - 0 (I'll use a socket, so I want to read the resistor from the cable).

https://www.evalbo.de/download-1/

Some useful stuff

Macrisu, 2019-07-18:
On the german forum, somebody had the same issues and the problems seemed to be D1 (defective)
https://www.goingelectric.de/forum/viewtopic.php?t=31260

Macrisu, 2019-07-18:
Well...
I try to activate Modbus - 5x press on the button on the first 3 seconds after power-on, but no success :(

I get Modbus error in the WIFI interface.

hgmendes, 2019-07-18:
Normally Modbus error is D1/D2 > TX/RX crossed or Modbus register not
activated. Try to do it faster.

Hugo Mendes
GSM PT: +351 916 903 578
Skype: hgmendes

Macrisu <notifications@github.com> escreveu no dia quinta, 18/07/2019 à(s)
14:14:

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

Macrisu, 2019-07-18:
I'm getting mad with this...
I cannot activate modbus :(

Also, in the EVSE WIFI Settings, I get no info about Device Status
Also, the LOG is always empty
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

hgmendes, 2019-07-18:
What is the version of SimpleEVSE firmware? Not all versions have modbus
activation on boot. Does the LED stays on for a few seconds on boot or
start immediately to blink?

Device status only appears when modbus connection is ok.

Hugo Mendes
M: +351 916 903 578

A quinta, 18/07/2019, 19:30, Macrisu <notifications@github.com> escreveu:

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

Macrisu, 2019-07-18:
It works...
I've forgot to connect the GND wire :(

All working great now, even RFID 💃

hgmendes, 2019-07-26:
How are you powering the NodeMCU? I think my problem could be there, since
i'm powering it from SimpleEVSE 5v...

Hugo Mendes
GSM PT: +351 916 903 578
Skype: hgmendes

Macrisu <notifications@github.com> escreveu no dia quinta, 18/07/2019 à(s)
20:33:

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

Macrisu, 2019-07-26:
I’m using an US chromecast adapter 5v, 1a
I finally got an use for US and UK phone adapters...

Bogdan Gheorghe
+40743188002

________________________________
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

Macrisu, 2019-08-17:
Well, I have your problem now, and the culprit is the power supply.
It says 1A 5V and worked for few days, but now I have disconects after few minutes.
I’ll use a Well Din Rail power supply via usb.

hgmendes, 2019-08-26:
Hi,

My problem was solved connecting 5v from ac/DC converter to esp, I presume that 5v delivered by SimpleEVSE wasn't enough.

Closed 2019-11-22.

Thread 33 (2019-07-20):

How to reset WIFI settings?

Macrisu, 2019-07-20:
Hello!
If for some reason I need to reset the ESVE-WIFI settings to default (Access Point), how can I do it?
Is there a hardware way?

I need to move my box go another location and I need to change the WIFi SSID to connect.
If I forget to reset the AP-Client mode, how can I access the WIFi interface on the new location?

CurtRod, 2019-08-30:
If the configured WiFi is not found in client mode, EVSE-WiFi starts in fallback mode. In fallback mode, EVSE-WiFi starts as AP and restarts every 10 minutes. Within these 10 minutes, you can use the web interface to configure your new WiFi in client mode.

Macrisu, 2019-08-31:
Now I know that via trial and error.
Thank you for reply.
Also see please the problem with the button.

CurtRod, 2019-09-04:
Do you mean the button issue, which is discussed in goingelectric.de?

Macrisu, 2019-09-04:
Yes, that issue..

Bogdan Gheorghe
+40743188002

________________________________
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

CurtRod, 2019-09-04:
The Button must be connected as described in README.md:
NO -> D4 (GPIO2 on ESP)
COM -> GND
You have to activate the button also in the settings page in the WebGUI of EVSE-WiFi.

CurtRod, 2019-09-08:
Did it work?

Closed 2019-11-22.

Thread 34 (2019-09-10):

Port forwarding problems?

Macrisu, 2019-09-10:
I try to access my EVSE from the internet. I've forwarded the external port 1234 to port 80 of my EVSE.
I can access the login page, but nothing is happening when I press the login button.

Do I need to do something else? To forward another port?

Macrisu, 2019-09-16:
I've forwarded only the TCP port.
Do I need to forward the UDP port, also?

hgmendes, 2019-11-04:
Hi Macrisu,

Forwarding TCP 80 and UDP 80 port i can access from outside...

However would be interesting that we could define in which port SimpleEVSE Wifi is listening for that we can use a different port rather than 80 since this port could be in use for other appliances also or even for the router, and some routers couldn't be configured with other port rather than 80.

rtfmjoey, 2020-01-11:
I'm using a reverse proxy and in addition to standard http protocol it's also needed to proxy the websockets protocol. The UDP protocol isn't needed.

Example:

<IfModule mod_ssl.c>
	<VirtualHost *:443>
		ProxyRequests Off
		ProxyPreserveHost On
		ProxyVia On

		ProxyPass /ws ws://192.168.40.31/ws
		ProxyPassReverse /ws ws://192.168.40.31/ws

		ProxyPass / http://192.168.40.31/
		ProxyPassReverse / http://192.168.40.31/

		ServerName evse.domain.example
		ServerAdmin webmaster@domain.example

		ErrorLog "/var/log/apache2/evse.domain.example-error_log"
		CustomLog "/var/log/apache2/evse.domain.example-access_log" common

		SSLCertificateFile /etc/letsencrypt/live/evse.domain.example/fullchain.pem
		SSLCertificateKeyFile /etc/letsencrypt/live/evse.domain.example/privkey.pem
		Include /etc/letsencrypt/options-ssl-apache.conf
	</VirtualHost>
</IfModule>

Using a Let's Encrypt SSL certificate the EVSE is now accessible via https from the outside world.

mkrasselt1, 2020-09-28:
Its not the port thats Causing the Problems, Press F12 in your Browser and Check the Konsole for Warinings and Errors. The should be some "insecure websocket not allowed outside personal networks" of some sort which is cuased by the browser rejecting the (because the lack of power in the esp8266) insecure websocket connection over the internet. of course you can disable the feature but @rtmfjoey 's solution is way better

Macrisu, 2022-03-27:
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

I've done this and I can access the EVSE via HTTPS
The problem is now, that I can not log in!
After entering the password, the WIFI connection is lost for some reasons ;(

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

No such problem via LAN

schenlap, 2022-07-04:
I discovered a problem regarding port forwarding. The evse website always connects to websocket port 80/ 443, regardless of website port (may be different for forwarding).

```
function wsConnect() {
  var protocol = "ws://";
  if (window.location.protocol === "https:") {
    protocol = "wss://";
  }

  wsUri = protocol + window.location.hostname + "/ws";
  websock = new WebSocket(wsUri);

```

Maybe https://www.w3schools.com/jsref/prop_loc_port.asp could help to get port of current url and use this for websocket connection (to also use the forwarding).

mkrasselt1, 2022-07-09:
i think this is because insecure websocket is not allowed on https websites - do you use reverse proxy for adding https ?

Macrisu, 2022-07-09:
I tried with reverse proxy https and without reverse proxy, simple port fwd.

Same problem.

mkrasselt1, 2022-07-16:
could you use a vpn?
As i wont be that confidend to expose this web-api to the public

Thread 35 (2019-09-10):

Charge stops when ventilation start

hgmendes, 2019-09-10:
Hi,

I've implemented this version in an ESP8266 and when charging Renault Zoe's the charge stops when AC starts to cool the batteries. I've already tried with almost 10 Zoe's and the problem is always the same. If we use SimpleEVSE as provided without modifications problem doesn't occur, problem only occur when power off by software is activated. As when Zoe start to cool batteries the charge is paused for a few secondsand then won't reactivate!
I'm thinking to develop a kind of timer for that charge can restart... any comments?

hgmendes, 2019-10-02:
Any comments regarding similar cenario? Any one else with Zoes?

CurtRod, 2019-11-04:
Sorry for the late reply. Is it correct, that Zoe stops charging for a few minutes when ventilation starts? There is a timer checking, if the vehicle is already charging. It would be possible, to set up this timer, so the charging will be interrupted by EVSE-WiFi later. Can you tell me how long Zoe interrupts charging when ventilation starts?

hgmendes, 2019-11-04:
Hi Curt,

Thank you for your reply.
The Zoe could take from 10 to 60 seconds to reactivate charging after
ventilation start.
I have feedback now that also occurs with other models like Kia e-Niro and
Hyundai Kauai.

Hugo Mendes
GSM PT: +351 916 903 578
Skype: hgmendes

CurtRod <notifications@github.com> escreveu no dia segunda, 4/11/2019 à(s)
18:25:

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

CurtRod, 2019-12-15:
can you reproduce this error with Version 0.3.0? Is there a difference in "normal mode" or if you using "always active"?

hgmendes, 2019-12-17:
Hi Curt,

I've didn't yet made the update, i've just made a change to 2005 register
to 0 and problem has stopped, but i've lost the RFID activation function...

I will try to update this weekend and i will let you know.

Regards,

Hugo Mendes
GSM PT: +351 916 903 578
Skype: hgmendes

CurtRod <notifications@github.com> escreveu no dia domingo, 15/12/2019 à(s)
21:28:

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

hgmendes, 2019-12-19:
Problem continues even on the new 0.3.0 version.
eGolf also have problems to charge with RFID activation, when 2005 register set to 0 it possible to charge without problem

CurtRod, 2019-12-20:
did you also try the "always active mode"?

hgmendes, 2019-12-21:
Yes, in “always active mode” works fine. Problem only occurs when using
cards or button (in app or physical) to activate EVSE.

CurtRod <notifications@github.com> escreveu em sex, 20/12/2019 às 16:03 :

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
--
Sent from MetroMail

premultiply, 2020-08-17:
RFID authorisation and other internal parameters should only be reset on car connect/disconnect but never when just contactor switching is done with cable connected.

DavidMenting, 2021-01-11:
I can confirm that the Hyundai Ioniq is affected by this issue as well. Charging stops after a few minutes in normal mode. In always active mode charging works fine altough it is then impossible to start or stop the charging session.

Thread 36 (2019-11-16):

„Always active“ function

noelbuechte, 2019-11-16:
Hi,

My Model 3 has a new function called „sheduled charging“. It will start charging on a calculated time.

While it is waiting, it often activates charging for a few seconds, what will deactivate EVSE, so it can‘t start on the calculated time.

Can you please impement a function like „always activated“ or „stay on for 24h“....?

Kind regards
Noel

rtfmjoey, 2019-11-21:
I would also like this!

Especially with preheating this would be a great feature.

CurtRod, 2019-11-29:
this feature will be added with version 0.3.0. I hope I can release it this weekend.

CurtRod, 2019-12-03:
resolved with update to 0.3.0

Closed 2019-12-03.

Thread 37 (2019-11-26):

Enhancement: Add fault detection via GPIO

rtfmjoey, 2019-11-26:
I've bought a residual current detector to detect any DC leakage > 6mA (see http://www.stegen.com/en/ev-products/126-residual-current-sensor.html for details and datasheet).

The RCD signal wire is connected to a relay with takeover contacts which cuts power to the contactor relay and disconnects the CP line in the event of current leakage.

This works like a charm but there is no feedback (aside from a led lighting up) and needs manual reset by switching the mains off and on again.

Is it possible to add a fault or error state triggered via a GPIO pin? (signal wire is high when a fault is detected and low when the fault is cleared. As the RCD uses 12V an optocoupler or transistor is required.)

In the event of DC leakage the EVSE needs to be switched off and cannot be enabled by button/rfid/api etc until the signal wire is log again and the error state is reset via the GUI (for example, the Activate/Deactivate button can be used to clear the error state).

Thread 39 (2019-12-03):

Charge duration not reset

rtfmjoey, 2019-12-03:
I'm testing to let Domoticz switch off the EVSE via the API when power usage thresholds exceeds and noticed that the charge duration is logged wrongly sometimes.

The duration in EVSE always starts at 00:00 and stops counting when EVSE is deactivated but the logged duration looks like some counter is not reset sometimes after EVSE is deactivated:
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

Anyone else seen this (is this a bug)? I'm using version 0.3.0 but also experienced this sometimes with 0.2.8

rtfmjoey, 2019-12-05:
Hm, strange things are happening...

I noticed that the NodeMCU sometimes reboots when deactivating the EVSE, after that the charge duration is displaying the weird values.

Also, when charging shortly everything is logged correct but if charging is running for a longer time the charged energy is not logged (just displays the circle arrow).

When connecting a serial terminal I see all kind of exception (2 and 3 mostly). I swapped the NodeMCU (original Amica 1.0) already but it shows the same issue.

At this point I'm beginning to suspect the power supply. Although it's specced at 5V 1A (hilink) I think that it's not enough or dips at certain times (i.e. when writing to spiffs and transmitting packets over wifi). Because it's enclosed it's running a bit warm (not hot!). I'll source a power supply which can supply more power, swap it out and see what happens.

rtfmjoey, 2019-12-07:
I swapped the power supply last night for a 2.5A model and the NodeMCU seems stable (no crashes, restarts or poorly connecting to WiFi anymore). To be sure I added decoupling capacitors directly to the VIN/GND and 3V3/GND pins.

However, the issue with the charging time remained. It seems that there is an issue with getChargingTime() or updateLog (getting skipped or millisStartCharging = 0; is not executed properly).

I've reverted to 0.2.8, which I recompiled as discussed in https://github.com/CurtRod/SimpleEVSE-WiFi/issues/28#issuecomment-557041613 and everything seems to be working correctly now.
The charge duration is logged correctly everytime (tested via a mix of API, GUI and button requests with variation from 5 seconds to 2 hours).

I'll continue to test to see if things remain stable but it seems like some bug is introduced on 0.3.0

rtfmjoey, 2019-12-15:
After some days of testing I found that the issue was completely resolved with the new power supply. Even with 0.3.0 the durations are logged normally.

I did find a bug in the charge duration when 'always active' mode is used. The millisStopCharging = millis(); is only executed when not in always active mode. I'll close this issue and will open a new one for the bug.

Closed 2019-12-15.

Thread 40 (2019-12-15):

Charge duration not correct when using 'always active'-mode

rtfmjoey, 2019-12-15:
When using the 'always active' mode of version 0.3.0 the charge duration is not calculated correctly because 'millisStopCharging = millis();' is only executed when _not_ in always active mode.

After changing line 782-785 from

       if (vehicleCharging) {  // EV interrupted charging
          vehicleCharging = false;
          toDeactivateEVSE = true;
        }

to

        if (vehicleCharging) {  // EV interrupted charging
          vehicleCharging = false;
          toDeactivateEVSE = true;
          millisStopCharging = millis();
        }

calculation is done correctly in always active mode.

CurtRod, 2019-12-15:
I've seen that too. Will be corrected in the next few days with update to 0.3.1.

rtfmjoey, 2020-01-11:
Issue was resolved succesfully in 0.3.1

Closed 2020-01-11.

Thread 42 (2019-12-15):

Enhancement: Disable/Enable EVSE when using always on-mode

rtfmjoey, 2019-12-15:
Is it possible to add a feature to allow enable/disable of EVSE via API when using always-on mode? (or some other form of administrative on/off - allowed/not allowed to charge)

I've integrated with Domoticz to balance charging current and when max current is exceeded the EVSE is disabled so I don't blow the main fuses.

In always-on mode this is not possible atm, the EVSE is not deactivated when setStatus?active=false is used.

CurtRod, 2019-12-15:
That is correct. In always active mode EVSE will never be deactivated. This feature may come with version 0.4.0.

CurtRod, 2020-03-15:
use the API to set Current to 0:
`http://YOURIP/setCurrent?current=0`

andig, 2020-08-13:
@CurtRod coming from https://github.com/andig/evcc I'm confused which API to use. In the past I've used `setStatus` which still seems to exist but you're recommending `setCurrent`. When would I use the one or other?

Closed 2020-03-15.

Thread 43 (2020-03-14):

Evse-wifi 0.4.0 said password?

Macrisu, 2020-03-14:
I’ve upgraded to 0.4.0 version yesterday (now is a newer version).
After update, my wifi is now password protected on the ssid!

Is very hard for me to access the module.
What is the wifi pass? It was initially open (no wifi pass)

Macrisu, 2020-03-14:
Now I know how to erase a NodeMCU.

You need to install Python on Windows 10.

https://www.digitalocean.com/community/tutorials/how-to-install-python-3-and-set-up-a-local-programming-environment-on-windows-10

After installation, run those commands in Powershell Admin mode:

```
python -m pip install --upgrade pip
pip install pyserial
pip install esptool
```

The command to erase the flash is:

`esptool.py -p com5 erase_flash`

Modify com number as needed in your case.

This will reset the ESP8266 to defaults.

CurtRod, 2020-03-15:
I don't have any idea why there was a password set. I tried to reproduce this issue but could understand this bug.

bauer1980, 2020-03-15:
Yes, It askes for username and password after logging in with adminamin - after the first startup. I can't change and access settings.

Macrisu, 2020-03-15:
Use Chrome, as the safari option from settings doest not seems to work.

bauer1980, 2020-03-15:
great,
thank you for the quick support.

yes, it didn work with safari and firefox, but with chrome.

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

bauer1980, 2020-03-15:
hi, sorry to disturb again,
it only works at the first login,
unfortunately i interrupted,
and now it also asks me with the chrome for a user and a password after using „adminadmin“ at the login page.

thank you for any suggestion!

best regards,
Wolfgang

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

Macrisu, 2020-03-15:
Use refresh in Chrome.

It will go away.

In the settings deactivate the basic auth.

CurtRod, 2020-03-18:
did this solve the problem?

bauer1980, 2020-03-18:
i am not sure. i used chrome, on the phone and the laptop and tried it many times and suddenly it worked. After deactivate the basic auth. for safari use, it works without problems.

mpolak77, 2020-04-26:
I think my issue is similar - I‘ve updated to 0.4.x and suddenly I cannot associate to the
evsewifi AP anymore. It used to be wpa2 before but now it seems my original WiFi password does not work or something else is broken. Since the upgrade it seems to be running in always on mode

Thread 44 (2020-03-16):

change evse register with web ui - change modbus value

bauer1980, 2020-03-16:
Hello,
i can access and change evse wifi settings, i can also see evse register on "show device status" - but i have the problem that i cannot change the register values. If i set them they don't change. Also after restart they are not changed.
I have on register 2001 following value: 25973, i want to change it to 1 but it does not work. I always get modbus error on the main page. I checked all wire connection, i cannot find the problem.
Also if i put the AN pin 5 times to 0 within the first 3 seconds of start i don't get anything changed.
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

bauer1980, 2020-03-17:
Issue solved: I didn't connect GND --> GND from EVSE DIN to the ESP8266

CurtRod, 2020-03-18:
sorry, for the late reply. It looks like there is no connection to EVSE DIN. It also should show you the "Modbus error" on the "EVSE Control" Page.

Closed 2020-03-18.

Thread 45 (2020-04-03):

Additional S0 meter for limitation of charging current based on house consumption

urbanperme, 2020-04-03:
I was thinking how to limit the current based on fuse size in my house.

For example:
If I have 20A fuses on single phase, and have consumption of 5A for house appliance, I could set the max charge current to 15A. But in case the consumption increases from 5A to 10A then I would like automatically change the maximum charging current to 10A, and vise versa. In this case the car would take as much as he could to have faster charging.

Is there any way to add additional S0 meter to a different GPIO and make the calculation of max current based on that?

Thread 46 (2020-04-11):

Clarify JSON api response structure for getParameters

andig, 2020-04-11:
I'd like to support SimpleEVSE-WiFi as part of https://github.com/andig/evcc.

Reading https://www.evse-wifi.de/dokumentation/#HTTP_API I find the JSON structure not matching the code (https://github.com/CurtRod/SimpleEVSE-WiFi/blob/master/src/main.cpp#L1002). According to the code, all elements are prefixed with `evse_` and not using camel case.

Since I don't have a SimpleEVSE Wifi for testing, could you please clarify which JSON structure can be expected?

mkrasselt1, 2020-09-28:
i have version 0.4.1 and it outputs:
`{"type":"parameters","list":[{"vehicleState":1,"evseState":true,"maxCurrent":20,"actualCurrent":10,"actualPower":0,"duration":0,"alwaysActive":true,"lastActionUser":"vehicle","lastActionUID":"vehicle","energy":0,"mileage":0,"meterReading":25.18,"currentP1":0,"currentP2":0,"currentP3":0}]}`
i dont expect this to be changed in later versions

andig, 2020-09-29:
Perfekt, thank you!

Closed 2020-09-29.

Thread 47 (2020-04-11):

Simplify API usage

andig, 2020-04-11:
Set `setStatus` and `setCurrent` commands always return HTTP 200, even in case of failure (https://github.com/CurtRod/SimpleEVSE-WiFi/blob/2104dec5209eca9c0a3275c3120dc27320290686/src/main.cpp#L1558). It would be great to return HTTP 400 in that case to make usage compatible with typical REST API patterns and client libraries.

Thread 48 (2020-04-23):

Documentation: electrical schema

neographikal, 2020-04-23:
Fantastic project and the ESP-side of the project is well documented. It would help me a lot to have an electrical schema as well where I can see which pin from the SimpleEVSE (DIN) I would connect to what.

This would be very helpful to wire everything up and order the needed components. Could this be added to the readme.md?

Macrisu, 2020-04-23:
Here are the plans
https://www.evalbo.de/download-1/

neographikal, 2020-04-24:
Thanks nice that helps, my German is a bit rusty, but I can figure it out. It would be nice to have an English version here in the repo to glance at :)

Closed 2020-04-24.

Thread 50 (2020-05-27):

Limited to 3kW?

Macrisu, 2020-05-27:
Hello!
I have a leaf 2019 40 kWh, which is using only one phase and max 6.6 kW to charging => 32A tree phase.

This is my second EVSE, but the first with a cable.
I've put a 220 OHM resistance between PP and PE for 32A on the cable

[180924 analoger Steuereingang Simple EVSE WB.pdf](https://github.com/CurtRod/SimpleEVSE-WiFi/files/4691771/180924.analoger.Steuereingang.Simple.EVSE.WB.pdf)

I use the Modbus version.

The problem is that I'm limited to 3 kWh, as reported by the car.
I've tried with another EV station and I get 6 kW.

Where should I start looking?

premultiply, 2020-05-27:
There have to be matching PP resistors on both ends of the cable. One on car side and one on EVSE side. There is no wire connection between them!
Both, car and EVSE detect the cable capabilities on "their" resistor. Thar will not drew more current than allowed and the EVSE will not signal a higher current as allowed by its resistor as PWM to the car. So there is double safety.

On other EVSE-systems the resistor on EVSE-side may be replaced by internal register setting only but the resistor on car's side is always requiered.

Macrisu, 2020-05-27:
As I said, what both ends of the cable?
I have one 220 OHM resistor inside the male connector that enters the car.
The other side of the cable is connected to EVSE.

See the PDF on the first post.

hgmendes, 2020-05-27:
You also need to put a 220ohm resistor between PP connection and ground on
SimpleEVSE.

Hugo Mendes

A quarta, 27/05/2020, 22:09, Macrisu <notifications@github.com> escreveu:

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

Macrisu, 2020-05-27:
Even if I use modbus?
I need to put that 220 ohm resistor on evse?

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

premultiply, 2020-05-27:
Yes. As written on both ends if the cable.
The car needs one and the EVSE needs one.

Macrisu, 2020-05-27:
I’ve put the second resistor on evse gnd-pp and is working now!
Than you all
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

Closed 2020-05-27.

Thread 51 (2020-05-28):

EVSE Firmware

Macrisu, 2020-05-28:
This question is about EVSE, not WIFI.
I see new firmware and I have a Pickit 3.

http://evracing.cz/evse/evse-wallbox/

Does anybody know the difference between those two?

`evse-wb_modbus_rev15_20200217_stateDpower0.hex (17164)
evse-wb_modbus_rev15_20200217_stateDpower1.hex (17164)`

**2020-02-15 revision 15:**
- added minimum pilot_high condition (fix for Metrel A 1532 – status E/F test)

CurtRod, 2020-07-26:
Dpower0: State D (charging with ventilation) is not allowed by EVSE
Dpower1: State D (charging with ventilation) is allowed by EVSE

Closed 2020-07-26.

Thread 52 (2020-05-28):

EVSE Always active mode - debug active automatically

Macrisu, 2020-05-28:
Hello

I'm using 0.4.1 with Always active mode ON and Disable BasicAuth (Safari Mode) ON

On save & restart, I get the Debug mode ON automatically.

I tried on two devices, the same problem.

CurtRod, 2020-07-26:
this bug is fixed in v1.0.1

Closed 2020-07-26.

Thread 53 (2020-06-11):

API calls from different devices cause non-responsiveness

FrenkK, 2020-06-11:
I use Home Assistant to check the EVSE status and a separate program to set charging current according to available power.
The Home Assistant readout works well on it's own and charging current setting via API works as well, when they are working separately. But if both are working, the system stops responding to everything, both webpage server and API responses until I reset.
I assume it must be a problem when API call happen at the same time and this causes something to break.

mkrasselt1, 2020-09-28:
the small webserver of the esp cant handle more then one concurrent session - consider lowing the polling intervall and try routing the output of your program back through home assitant - mine is using an automation to set the power evertime the inverter gives me new power readings

FrenkK, 2020-09-29:
This is what I did, but it seems that the problem should be handled better.
I understand the hardware limitation, but the error should be handled more gracefully instead of having to reset everything each time.

mkrasselt1, 2020-09-30:
you actualy dont have to reset it - because when the resources are free again, it starts responing again - if not you are flooding this smal thing with requests

FrenkK, 2020-09-30:
It does recover on it's own, but it takes a long time.

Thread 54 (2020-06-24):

Charged energy reset should be tied to car connection status

FrenkK, 2020-06-24:
This is not really a bug, more a problem with concept.
**Problem:**
Currently, the system counts the energy and resets the count each time the EVSE is turned off. If you turn the EVSE on and off during charging via API (e.g. for time control or power limitation), you get several separate energy totals, even though the car was connected all the time and it should count as one charge.
**Solution:**
It would make much more sense to reset the charged energy each time the car connection status goes from 1 (EVSE ready) to 2 (Car connected). This would ensure the energy is added up properly until the car is finally disconnected. It would then reset on next connection of car, keeping the value ready to read via API until then.

andig, 2020-08-17:
I would like to support this request. Discussions on https://github.com/andig/evcc show that users are interested in total energy charged. Especially in PV mode this can come with interruptions. EVSE should just relay the actual meter measurements or reset on connect/disconnect only.

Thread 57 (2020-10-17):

Can't connect to wifi 802.11g

Wiednitz, 2020-10-17:
wemos d1 pro with evse wifi does not connect to router with wifi 802.11g, only with 802.11b.

(Same problem with sonoff with tasmota version 8.x, version 6.3 can connect wifi g)

Whats the reason ? Bug in arduino/platformio libraries ?

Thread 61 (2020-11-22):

Ladung startet manchmal nicht mit 2.0.4

schenlap, 2020-11-22:
Seit ich auf 2.0.4 upgedated habe startet die Ladung nicht. Normalerweise verwende ich evse im Remote mode mit evcc. Wenn es sort hängt bringt auch ein umschalten auf den Normalmode nichts.

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

Auch nach mehreren Minuten startet die Ladung nicht. Erst nach mehreren Reboots (zwischen Remote- und Normalmode umschalten) hat die Ladung gestartet.

schenlap, 2020-11-22:
`{"type":"parameters","list":[{"vehicleState":2,"evseState":true,"maxCurrent":16,"actualCurrent":6,"actualPower":0,"duration":3066,"alwaysActive":true,"lastActionUser":"API","lastActionUID":"API","energy":0,"mileage":0,"meterReading":0,"currentP1":0,"currentP2":0,"currentP3":0,"useMeter":true}]}`

schenlap, 2020-12-07:
Heute ist es das erste mal auch im Echt-Betrieb aufgetreten. Nur die Box neustarten hat das Problem behoben. Wenn man über die API einen Stromwert vorgegeben hat habe ich eine korrekte Antwort erhalten, es ist aber nichts weiter passiert.
`S0_set current to given value`

CurtRod, 2020-12-29:
sorry für die späte Rückmeldung. Besteht das Problem nach wie vor? Welchen Stromzähler verwendest du denn?

schenlap, 2020-12-30:
Es ist jetzt schon einige Zeit nicht mehr aufgetreten, ich werde weiter beoabachten.
Stromzähler ist intern ein S0 Zähler.

schenlap, 2021-03-23:
Ist jetzt schon lange nicht mehr aufgetreten

Closed 2021-03-23.

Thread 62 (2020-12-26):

API - getLog Crash

JFK344, 2020-12-26:
Get Log is not working when loging is disabled or the log is empty. The Problem ist that the ESP will crash and not recover.

CurtRod, 2020-12-29:
thank you for reportig this bug. Will be fixed in one of the next updates

JFK344, 2021-01-02:
Thank you! I have developed a IoBroker Adapter for the ESVE Wifi.  [https://github.com/JFK344/ioBroker.esvewifi]

edsub, 2023-01-31:
Thus issue is still present I think?

Macrisu, 2023-01-31:
Last update for this free version was a long time ago so…
I’ve used Etek chinese controller and accesories and is very stable.
If you need PV control, I recommend Go-e charge with phase change.

JFK344, 2023-01-31:
> Last update for this free version was a long time ago so… I’ve used Etek chinese controller and accesories and is very stable. If you need PV control, I recommend Go-e charge with phase change.

? who said anything about pv controll ?

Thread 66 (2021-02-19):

Recompile 1.x version to work on ESP32 ?

Macrisu, 2021-02-19:
Hello,

It is possible to modify/recompile version 1.x to run on an ESP32?

https://maker.pro/esp8266/tutorial/how-to-upgrade-from-esp8266-to-esp32

CurtRod, 2021-02-28:
You can compile the existing code also for ESP32.

Macrisu, 2021-02-28:
I will try...
From what I see here, Arduino is not needed?
https://github.com/CurtRod/SimpleEVSE-WiFi/pull/65

HA-TB303, 2021-03-03:
That sounds great, I need the same for my little DIY charger DIN Rail thingy ;)
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

Macrisu, 2021-03-04:
@hoermto I used NoddeMCU and for some reason, they are crap and cannot connect to them after firmware upgrade.
Also, WIFI is very bad.
I've ordered two ESP32-WROOM-32U and WIFI antenna.

If you can compile the 1.x firmware for ESP32 it would be great.

hoermto, 2021-03-04:
I am using a NodeMCU 8266 currently. Wifi is bad, yes. Other is that it has no free Pins to extend with Oled or CPInt.
It will need some time on my side to get it done, however, I have the same plan. Using a ESP32 with external antenna to use in my SimpleEVSE v1.

hoermto, 2021-03-04:
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

For this case, what is you requirement? You can compile the code for the Wemos D1 mini still ... if you migrate to ESP32, you pin layout will change, so I suspect you cannot use this hardware directly.
In reverse, you wont be able to get all EVSE-WIFI v2 features into the 8266 because of limited pin count and 8266 memory shortage (e.g. OLED libraries won't fit into the firmware). There are ways, like if you dont have a RFID, you could use these pins for a CPInt (requires code changes).
There is a high number of combinations of ESP versions across different features which might be connected in different ways (e.g. EVSE connected via software-serial or HW serial). The maintainer of this project has a clear scope of the software, which might stay in conflict with other peoples ideas.

So, regarding your HW setup, what would be your requirement? Just being interested :-)

HA-TB303, 2021-03-05:
Hi, when using the wemos d1 mini (esp8266) the following GPIO's are exposed on the terminals:

D1 true D8.

That translates to the MH-ET Live esp32 as:
Wemos D1 mini -> MH-ET-live esp32
D1 (GPIO20) -> GPIO22
D2 (GPIO19) -> GPIO21
D3 (GPIO18) -> GPIO17
D4 (GPIO17) -> GPIO16
D5 (GPIO14)-> GPIO18
D6 (GPIO12)-> GPIO19
D7 (GPIO13)-> GPIO23
D8 (GPIO15)-> GPIO5

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

HA-TB303, 2021-03-06:
Hi @hoermto we found a better PSU for the job and are in the process of redesigning the PCB.  It's a universal Wemos D1 mini / MH-ET live esp32 design, but If you can let me know what GPIO's would be ideal for the esp32 version of the Simple-EVSE-Wifi, we will expose those!

This design will be shared on our website in due time, so everybody can build it themselves.

Concept design:
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

HA-TB303, 2021-03-06:
SPI is definitely not doable within this form factor. The display would have to be I2C driven (SDA/SCL). If the code could be adjusted to that, I could have GPIO 26, 18, 19, 23, 5, 17 and 16 free for other stuf, along with TX and RX.

hoermto, 2021-03-06:
You D1-D8 exposed. It depends on what meter you use and what meter you want to use, also whether RFID is used or not.
Minimum is D1/D2 for EVSE connection when not using Modbus. With the rest you might use OLED, CPInt and button (or LED) if you dont use RFID. If you use a Modbus Meter, you could use the LED and Button, since the D3 for S0 is released. If you are using a Modbus over RS485, you also could connect the EVSE over Modbus, and then have another D1/D2 release.

There are many options. It all depends finally from the hardware layout. If you want to remain pin-compatible between D1-mini and D1-mini-32, only D0-D8 + TX/RX from D1-mini and their equivalents of D1-mini-32 are available.
As an additional option, the TX and RX pins should be possible to to used aditional digital in/out as well. With this you can add more features to your layout. However, this would require to run EVSE via D1/D2 (not Modbus), and would require commenting out the modbus meter from the code (currently always enabled, even if not used).

Here is the default PIN layout for the 2 versions available (Simple-EVSE 1.0 and 2.0 / SmartWB). If you can compile yourself, feel free to comment out what you don't need and reassign pins. As long as we cannot freely define the pin assignment via config, the compiled firmware follows this layout. Especially the change of the EVSE from Modbus to Serial and reverse is tricky if you are not familiar with all this.

For myself I am thinking to add some more config options to the software. However, compatibility to SimpleEVSE needs to be made sure in case it should have a chance for a merge.

Actually, as far as I know the EVSE-DIN module at least (the others as well I think) expose a 5v pin you could use for the EVSE-WIFI module. Use the free space for a relais for the CPInt probably? [http://evracing.cz/evse/evse-wallbox/evse-wb-din_20190712.pdf](url).

# pins EVSE-WIFI

|Module|Module PIN|SimpleEVSE 1.0<br/>Wemos D1 Mini|SimpleEVSE 2.0<br/>Wemos D1 Mini32|GND|3.3v|Remark
|:----|:-:|:-----:|:-----:|:-:|:-:|:------------------------|
|LED EVSE-WIFI|+|D0|26|x||optional
|EVSE|TX|D1|- (*4)|||using SoftwareSerial
|EVSE|RX|D2|- (*4)|||using SoftwareSerial
|EVSE|A|||||using RS485 bus A
|EVSE|B|||||using RS485 bus B
|SDM120<br/>SDM630|A|||||using RS485 bus A
|SDM120<br/>SDM630|B|||||using RS485 bus B
|RS485|TX|TX (*1)|TX|||Modbus interface
|RS485|RX|RX (*1)|RX|||Modbus Interface
|S0|data|D3||x||||So meter
|Button (Charge)||D4|16|x||optional
|Button (Reset)||Rst|Rst|x||optional
|RFID|Base|||x|x|
|RFID|SCK|D5|18|||(*2)
|RFID|MISO|D6|19|||(*2)
|RFID|MOSI|D7|23|||(*2)
|RFID|SDA|D8|5|||(*2)
|RFID|RST||22|||(*3) optional
|CPInt|S||4|x|x|
|RSE|||2|||(*5)
|Oled|cs||12||||
|Oled|dc||13||||
|Oled|reset||33||||

(*1) in SimpleEVSE 1.0 only for Modbus meter required. Currently occupied in any case.
(*2) RFID uses always first ictl pins from board. Cannot be changed
(*3) no pin on Wemos D1-Mini/8266
(*4) in SimpleEVSE 2.0 and SmartWB the EVSE is connected via Modbus only
(*5) "Rundsteuerempfänger" (receiver for external control), SmartWB only. Extra hardware required

HA-TB303, 2021-03-06:
Hi, thanks for elaborating this. At the chance of sounding really stupid now, in which file are the pins defined?

hoermto, 2021-03-07:
I did analyze the code and made this table for me in order to be ready for changes, which don't break the original design.
Maybe I can inject this into the repository later so it will be default documentation.

HA-TB303, 2021-03-07:
Ok thx. I’ll beter wait untill the open source support for the esp32 is more documented and supported then.

cola32, 2021-04-17:
@HA-TB303 where can I get such a board ?

HA-TB303, 2021-04-17:
Hi, We will publish a video and article on https://espthings.io soon where you can then get them made on pcbway.

cola32, 2021-05-14:
Cool thanks!

is it possible to use a version on an esp32 d1 mini?

Langer75, 2021-07-18:
Hi

one remarks:
- one pin is missing, what is the RST of the RFID? (like for oled pin 33)
Did you elaborate this too?

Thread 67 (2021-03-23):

meterReading liefert zu hohen Wert nach Ladeende

schenlap, 2021-03-23:
Hi,

wenn die Ladung beendet wird erhöht sich der meterReading Wert um die geladene Energie, siehe https://github.com/andig/evcc/issues/788
[evcc_20210323_meterReading.log](https://github.com/CurtRod/SimpleEVSE-WiFi/files/6191900/evcc_20210323_meterReading.log)

Eingesetzte Version: 2.1.1

schenlap, 2021-03-23:
energy stimmt, ebenso die Anzeige in der GUI.
Ich verwende einen S0 Zähler

schenlap, 2021-04-09:
aus dem evse-Beta Forum

`Edit: Der von dir genannte Bug wird tatsächlich mit der v2.2.0 behoben.`

thdietrich, 2023-07-21:
Von dem hier geschilderten Problem bin ich auch betroffen (Eingesetzte Version 1.1.1, letzte verfügbare Version für den ESP8266).

Gibt es eine Chance, dass eine neue Firmware für den ESP8266 mit dem Bugfix veröffentlicht wird?
Ich konnte das Problem und die Lösung im Quellcode (Zeile 2710ff in Version 2.2.2 in main.cpp) nachvollziehen
mir fehlt aber aktuell die Entwicklungsumgebung, um die Firmware zu erzeugen.

pjpeartree, 2024-04-15:
Hi,

Same, I am also facing the same problem on  version 1.1.1, last available version for the ESP8266, as reported at [https://github.com/evcc-io/evcc/discussions/13299#discussioncomment-9121240](url)

Any change to get the fix for ESP8266?

Regards,
Pedro

schenlap, 2024-04-16:
@pjpeartree
There was no activity in this repo for a log time.  Maybe you should report the bug on https://board.evse-wifi.de/viewforum.php?f=8

Closed 2021-04-09.

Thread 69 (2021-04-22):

GND needed? Wemos d1 Mini

cola32, 2021-04-22:
Hi,
I wanna connect my wemos d1 Mini to my Evse wb.
I have to connect tx (gpio5) and rx(gpio4)
Is gnd also needed ?
What’s are the differences between version 1.x.x and version 2.x?
Thanks for your help

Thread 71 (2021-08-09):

Interrupt CP Signal automaticly or by API

mkrasselt1, 2021-08-09:
We use remote controlled charging through homeassitant and excess solar engery,
but sometimes the car wont wake up automaticly so a CP interupt pressing is needed.
But manualy doing this removes all the usefullness of the api - so it would make a hell lot of sense
if the evse interrupts the cp signal eigther: permanently until charging starts, automaticly when charging starts after cars is present for x time or make it available through the api if possible.
i would add this myself but i dont have much time at the moment :/

Nebukadneza, 2021-11-26:
Hi,

check here:
https://github.com/CurtRod/SimpleEVSE-WiFi/blob/master/src/main.cpp#L3067
you simply go `curl -Xget http://<your-evse>/interruptCp` :tada:

mkrasselt1, 2021-11-27:
Thanks a lot, i updated and its working now :)

Closed 2021-11-27.

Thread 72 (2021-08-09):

Connect WeMos D1 mini to SDM630 Modbus ?

Macrisu, 2021-08-09:
Hello

I will use a TTL - RS485 converter [like this](https://www.aliexpress.com/item/1005001992729937.html?), but what pins should I use on the WeMos D1 mini ?

I will use the same D1 (RX) and D1 (TX)  like the EVSE - WeMos connection?
The instructions are blurry
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

Macrisu, 2021-09-01:
Sorry, fixed
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

Closed 2021-09-01.

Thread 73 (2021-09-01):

Improve WIFI Signal - SOLVED

Macrisu, 2021-09-01:
My biggest problem with the original WEMOS D1 Mini or Node MCU was the poor WIFi signal.

Now I've found and tested this, with external antenna.

WEMOS D1 Mini Pro 4M 16M Bytes External Antenna Connector NodeMCU Based ESP8266 ESP-8266EX CP2104 WIFI Development Board Micro

https://www.aliexpress.com/item/32801063577.html
It's much better and it's working!

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

kirk-loeten, 2021-09-02:
I use the same Wemos in other projects too. It is necessary to solder the bright from onboard antenna to the connector for the extern antenna.

Macrisu, 2021-09-02:
Usually yes, but i this case no need to solder.

https://www.aliexpress.com/item/32801063577.html
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

kirk-loeten, 2021-09-02:
https://hackaday.io/project/165061-solar-powered-wifi-weather-station-v20/log/162011-adding-an-external-antenna

Macrisu, 2021-09-02:
Uau, thank you! I did not know about this!
It seems really stupid to sell an external antenna and never say that in order to use it, you must modify the board.

edsub, 2024-01-31:
@Macrisu Did you succesfully flash the V1.1.1 firmware to a Wemos D1 mini pro (with 16M)?
If so:
1. Do you still encounter frequent crashes/reboots of the ESP when running? Especially when accessing the log?
2. What esptool parameters did you use to flash?
I flashed the v1.1.1 with that standard flash.bat to a Wemos D1 mini pro (with 16M) but still encunter frequent crashes/reboots. I exoect the reasoning is that with flashing a 4M bin to a 16M board effectively made my board act as a 4M . . . .

edsub, 2024-01-31:
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

Macrisu, 2024-01-31:
I don’t use this anymore.
Too unstable and now I can buy a Made in Germany charger, 11kw and 6.5m cable for 200 EUR.
It simply does not make sense to use Simple EVSE.
I have 3 boxes and some controllers.

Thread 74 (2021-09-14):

Max Current 25A, but 32A on Index

Macrisu, 2021-09-14:
Hello!

I use Current Firmware Version: 1.1.1
In the settings, I've put Max Current 25A and reboot.
On login, I see 32A for slider, not 25A

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

Macrisu, 2021-09-16:
Fixed:
https://github.com/CurtRod/SimpleEVSE-WiFi/issues/19

Closed 2021-09-16.

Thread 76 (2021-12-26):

unstable Wemos D1 mini build?

Langer75, 2021-12-26:
I downloaded the latest binary for Wemos D1 mini and flashed it. Unfotunatelly it is unstable. It crashes and restarts again. Unfortunatly it is not a systematic crash. It is random. It happens more often in acces point mode, but also sometimes in client mode. Does anybody knows this  issue? Does I made something wrong?

Macrisu, 2021-12-26:
Bad hardware. Try another Wemos.

Langer75, 2021-12-26:
that was my first guess too. But I have two Minis and both show the same behaviour. I bought a third one and also this is unstable. When I flash tasmota or espurna the Minis are stable. It is just with the binary V1.1.1. May I try an older Version.

hgmendes, 2021-12-26:
What’s your power source? Recommendable value is 1A

Langer75 ***@***.***> escreveu em dom., 26/12/2021 às 12:37 :

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
--
Hugo Mendes
M: +351 916 903 578
Skype: hgmendes

Langer75, 2021-12-26:
V1.1.0 is also not stable. My power source is 5V 2A. When I measure voltage and current it is 5.16V and less than 100mA. Does it makes a difference whether a EVSE is connected or not? For test puposes the evse is currently not connected. So I got Modbus error. But this should not crash the Wemos

Langer75, 2021-12-26:
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
These are my D1 Minis. One is 12F, one is 8266mod 12F and one is 8266mod only

Langer75, 2021-12-26:
By the way. Also with connected EVSE it crashes

hgmendes, 2021-12-26:
Maybe something is not ok with your power source, the two versions are very
stable..

Langer75 ***@***.***> escreveu em dom., 26/12/2021 às 14:53 :

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
--
Hugo Mendes
M: +351 916 903 578
Skype: hgmendes

Langer75, 2021-12-27:
I checked several 5V  power adapters. With all the same behavior. I have no further ideas. Which flasher tool do you use?

hgmendes, 2021-12-27:
Hi use the ESPtool in the project to upload bin but there are a lot of
similar softwares.

Langer75 ***@***.***> escreveu em seg., 27/12/2021 às 17:45 :

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
--
Hugo Mendes
M: +351 916 903 578
Skype: hgmendes

Langer75, 2021-12-28:
To exclude my flashing hardware as failure I let my friend flash one of my D1 mini. And after he has flashed the D1mini it was also unstable with evse-wifi firmeware. A lot of other binaries are working (e.g. tasmota, ESPeasy, ESPurna) without resets. But all of them have smaller binaries. Could it be, that the ROM has a defect, that only has an effect with the evse-wifi binary? It would be a bad fluke, that I have three Wemos D1 minis, bought seperatly with several month/years in between and all of them have the same error. Has someone made similar experiences. Is it somehow possible to check the ROM?

Btw.: I have ordered another one

royspeed, 2022-01-22:
I too have had problems with a Wemos D1 mini. Without being connected to the EVSE DIN everything seemed fine, but after connecting pin D1 D2 and GND, the green led on the EVSE is dim. With also 220V voltage on the EVSE the Wemos froze.
With different 5V 3A power supply the problem seems to be solved.

Macrisu, 2022-03-14:
I had a similar issue today when I've upgraded from NodeMCU to D1 Mini Pro with an external WIFI problem.
For some reason the D1 mini Pro clone does not power from the 5v pin and I had to use a cut cheap micro-USB cable from my 2.4A Power Source.

The cheap micro-USB cable was little long and was **close** to the 40A relay. This that poor shielding and I've got random crashes. I've moved the cable a few centimetres away from the 40A relay and no more problems.

edsub, 2024-04-23:
Did any of you solve this? i still have random crashes. I've read that the cause of this might be a too large firmware for the ESP. But since I am using an 8mb version and the memory usage in the gui not showing a teal shortage I think that should not be it.
I am using a micro-usb adapter to power the ESP.
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

rtfmjoey, 2024-04-23:
Are you using DHCP or static IP?

I've experienced frequent crashes until I switched from DHCP to static IP.

Langer75, 2024-04-23:
indeed I use static IP

edsub, 2024-12-16:
I am on static IP as well.

tux21, 2025-07-06:
Hi gyus, does anyone found the successful solution of this issue? I bought an evse module, several wemos D1's and oled, but I was not able to find a way where to connect the oled and it crashes after few seconds no matter what.. Project seems to be abandoned by the author so what was your solution? Dump it all and start with something else? I was pretty happy how it works and HA implementation, but it is very unreliable. It even stops charging once it crashes.

royspeed, 2025-07-07:
I could never get it stable either, and now, years later, it's still sitting in a box waiting. In the end, I decided to go with a SmartEVSE instead: https://github.com/dingo35/SmartEVSE-3.5.

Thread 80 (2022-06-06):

Tip: Use micro-usb to power ESP8266 (instead of 5V line)

edsub, 2022-06-06:
For some reason I thought the ESP8266 could be powered its +5V pin.
When you try to use the 5V pin you will notice that although some things do work, you will never see the WiFi get to life.
The solution is quite simple: Power the ESP8266 from the micro USB. I remember reading this somewhere else as well, but I thought to post it here for others.

Closed 2022-06-06.

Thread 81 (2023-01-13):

RFID devices limited

hgmendes, 2023-01-13:
I'm having some problems when registering more that 25/28 RFID tags, the list of registered tags disappears and i can't add any more tags.

Already tried to change ESP8266 to one with more quality and even D1 mini pro, but same thing happens.

Any similar situations?

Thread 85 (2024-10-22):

Lost connection while using

ichbins0815, 2024-10-22:
Hi there,
I found this software and like to use it in last Version 1.1.1.
I use a new D1 mini and the sw from smartwb.de v1.1.1
Wireing was easy and I can see some data from my WB.
If I change the charge-current I lost the connection.
Sometimes I lost connection without changing the current.
The same issue from Home Assistant.
I test it with different W-Lan; different EVSE and different D1 mini.
It doesn't matter using it as WiFi Client or Accesspoint.
The WiFi distance are around 1 Meter.

Can anybody help? Thanks

edsub, 2024-12-29:
I notice similar behaviour. Just log back in . . . .
More annoying is that the 1.1.1 versiion (with me) chrashes and reboots when I try to access the log. . . .

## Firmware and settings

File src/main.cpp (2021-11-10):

/*
  Copyright (c) 2018 CurtRod

  Released to Public Domain

  THE SOFTWARE IS PROVIDED "AS IS", WITHOUT WARRANTY OF ANY KIND, EXPRESS OR
  IMPLIED, INCLUDING BUT NOT LIMITED TO THE WARRANTIES OF MERCHANTABILITY,
  FITNESS FOR A PARTICULAR PURPOSE AND NONINFRINGEMENT. IN NO EVENT SHALL THE
  AUTHORS OR COPYRIGHT HOLDERS BE LIABLE FOR ANY CLAIM, DAMAGES OR OTHER
  LIABILITY, WHETHER IN AN ACTION OF CONTRACT, TORT OR OTHERWISE, ARISING FROM,
  OUT OF OR IN CONNECTION WITH THE SOFTWARE OR THE USE OR OTHER DEALINGS IN
  THE SOFTWARE.
*/
#include <Arduino.h>

#ifdef ESP8266
#include <ESP8266WiFi.h>              // Whole thing is about using Wi-Fi networks
#include <ESP8266mDNS.h>              // Zero-config Library (Bonjour, Avahi)
#include <ESPAsyncTCP.h>              // Async TCP Library is mandatory for Async Web Server
#include <FS.h>                       // SPIFFS Library for storing web files to serve to web browsers
#include <WiFiUdp.h>                  // Library for manipulating UDP packets which is used by NTP Client to get Timestamps
#include <SoftwareSerial.h>           // Using GPIOs for Serial Modbus communication

#else
#include <WiFi.h>
#include <ESPmDNS.h>
#include <SPIFFS.h>
#include <HardwareSerial.h>
#include "Update.h"
#include "esp_err.h"
#include "esp_log.h"
#include "esp_spiffs.h"
#include "esp_wifi.h"
#include "oled.h"
#endif

#include <TimeLib.h>                  // Library for converting epochtime to a date
#include <SPI.h>                      // SPI protocol
#include <MFRC522.h>                  // Library for Mifare RC522 Devices
#include <ArduinoJson.h>              // JSON Library for Encoding and Parsing Json object to send browser
#include <ESPAsyncWebServer.h>        // Async Web Server with built-in WebSocket Plug-in
#include <SPIFFSEditor.h>             // This creates a web page on server which can be used to edit text based files

#include <ModbusMaster.h>
#include <ModbusIP_ESP8266.h>

#include <string>
#include <iostream>
#include <deque>
#include "proto.h"
#include "ntp.h"
#include "syslog.h"
#include "websrc.h"
#include "config.h"
#include "templates.h"
#include "rfid.h"

uint8_t sw_min = 3; //Firmware Minor Version
uint8_t sw_rev = 0; //Firmware Revision
String sw_add = "";

#ifdef ESP8266
uint8_t sw_maj = 1; //Firmware Major Version
String swVersion = String(sw_maj) + "." + String(sw_min) + "." + String(sw_rev) + sw_add;
#else
uint8_t sw_maj = 2; //Firmware Major Version
String swVersion = String(sw_maj) + "." + String(sw_min) + "." + String(sw_rev) + sw_add;
#endif

//////////////////////////////////////////////////////////////////////////////////////////
///////       Variables For Whole Scope
//////////////////////////////////////////////////////////////////////////////////////////
//EVSE Variables
bool noEVSE = false;
uint16_t reg2005DefaultValues = 0;
bool highResolution = false;
uint32_t startChargingTimestamp = 0;
uint32_t stopChargingTimestamp = 0;
bool manualStop = false;
uint16_t currentToSet = 6;
uint16_t currentBeforeRemoteTimeout = 0;
uint8_t evseStatus = 0;
bool evseActive = false;
bool vehicleCharging = false;
bool timerActive = false;
int buttonState = HIGH;
int prevButtonState = HIGH;
AsyncWebParameter* awp;
AsyncWebParameter* awp2;
const char * initLog = "{\"type\":\"latestlog\",\"list\":[]}";
bool sliderStatus = true;
uint8_t evseErrorCount = 0;
bool doCpInterruptCp = false;
bool update1000 = true;
bool update2000 = true;
unsigned long updateInterval = 2000;
bool updateHelper1000 = false;
uint32_t mbErrCount = 0;
uint32_t mbReadCount = 0;

#ifndef ESP8266
unsigned long millisInterruptCp = 0;
bool rseActive = false;
uint8_t currentBeforeRse = 0;
#endif

//RFID
bool showLedRfidDecline = false;
bool showLedRfidGrant = false;
unsigned long millisRfidLedAction = 0;
unsigned long millisRfidReset = 0;
String lastRFIDUID = "";

//Metering
float meterReading = 0.0;
float meteredKWh = 0.0;
float currentKW = 0.0;

//Metering S0
uint8_t meterTimeout = 10; //sec
volatile unsigned long numberOfMeterImps = 0;
unsigned long meterImpMillis = 0;
unsigned long previousMeterMillis = 0;
volatile uint8_t meterInterrupt = 0;

//Metering Modbus
bool noSDM = false;
unsigned long millisUpdateMMeter = 0;
unsigned long millisUpdateSMeter = 0;
bool mMeterTypeSDM120 = false;
bool mMeterTypeSDM630 = false;
float startTotal;
float endTotal;
float currentP1 = 0.0;
float currentP2 = 0.0;
float currentP3 = 0.0;
float voltageP1 = 0.0;
float voltageP2 = 0.0;
float voltageP3 = 0.0;

//objects and instances
#ifdef ESP8266
SoftwareSerial SecondSer(D1, D2); //SoftwareSerial object (RX, TX)
#else
HardwareSerial FirstSer(1);
HardwareSerial SecondSer(2);
//oLED
unsigned long millisUpdateOled = 0;
U8G2_SSD1327_WS_128X128_F_4W_HW_SPI u8g2(U8G2_R0, /* cs=*/ 12, /* dc=*/ 13, /* reset=*/ 33);
//U8G2_SSD1309_128X64_NONAME0_F_4W_HW_SPI u8g2(U8G2_R0, /* cs=*/ 12, /* dc=*/ 13, /* reset=*/ 33);
EvseWiFiOled oled;
#endif

unsigned long millisOnTimeOled = 0;

ModbusMaster evseNode;
ModbusMaster meterNode;
ModbusIP modbusTCPServerNode;  //ModbusIP object
AsyncWebServer server(80);    // Create AsyncWebServer instance on port "80"
AsyncWebSocket ws("/ws");     // Create WebSocket instance on URL "/ws"
NtpClient ntp;
EvseWiFiConfig config = EvseWiFiConfig();
EvseWiFiRfid rfid;
//DynamicJsonDocument syslogJson(24576);
std::deque<String> syslogDeque;

unsigned long lastModbusAction = 0;
unsigned long buttonTimer = 0;

//Loop
unsigned long millisUpdateEvse = 0;
unsigned long millisRemoteHeartbeat = 0;
unsigned long currentMillis = 0;
unsigned long previousMillis = 0;
unsigned long previousLoopMillis = 0;
unsigned long previousLedAction = 0;
unsigned long reconnectTimer = 0;
unsigned long millisCheckTimer = 10000; // wait 10 sec to start timer
uint16_t remoteHeartbeatCounter = 0;
uint16_t toChangeLedOnTime = 0;
uint16_t toChangeLedOffTime = 0;
uint16_t ledOnTime = 100;
uint16_t ledOffTime = 4000;
bool wifiInterrupted = false;
bool ledStatus = false;
bool toSetEVSEcurrent = false;
bool toActivateEVSE = false;
bool toDeactivateEVSE = false;
bool toInitLog = false;
bool toSendStatus = false;
bool toSendSyslogToWs = false;
bool toReboot = false;
bool updateRunning = false;
bool fsWorking = false;
bool deactivatedByRemoteHeartbeat = false;
bool toSetSmartWb11kwFactorySettings = false;

//EVSE Modbus Registers
uint16_t evseAmpsConfig;    //Register 1000
uint16_t evseAmpsOutput;    //Register 1001
uint16_t evseVehicleState;  //Register 1002
uint16_t evseAmpsPP;        //Register 1003
uint16_t evseTurnOff;       //Register 1004
uint16_t evseFirmware;      //Register 1005
uint16_t evseEvseState;     //Register 1006
uint16_t evseRcdStatus;     //Register 1007
s_addEvseData addEvseData;

//Settings
bool useRFID = false;
bool dontUseWsAuthentication = false;
bool dontUseLED = false;
bool resetCurrentAfterCharge = false;
bool inAPMode = false;
bool inFallbackMode = false;
bool isWifiConnected = false;
String lastUsername = "";
String lastUID = "";
char * deviceHostname = NULL;
uint8_t maxCurrent = 0;
Syslog slog;

//Others
String msg = ""; //WS communication

//////////////////////////////////////////////////////////////////////////////////////////
///////       Auxiliary Functions
//////////////////////////////////////////////////////////////////////////////////////////

void ICACHE_FLASH_ATTR updateRemoteHeartbeat() {
  if (remoteHeartbeatCounter >= 60) {
    if (evseAmpsConfig > 0) {
      currentBeforeRemoteTimeout = evseAmpsConfig;
      toSetEVSEcurrent = true;
      currentToSet = 0;
    }
    deactivatedByRemoteHeartbeat = true;
  }
  else {
    if (deactivatedByRemoteHeartbeat) {
      toSetEVSEcurrent = true;
      currentToSet = currentBeforeRemoteTimeout;
    }
    deactivatedByRemoteHeartbeat = false;
  }
  remoteHeartbeatCounter ++;
  millisRemoteHeartbeat = millis() + 1000;
}

void ICACHE_FLASH_ATTR handleEVSETimer() {
  millisCheckTimer = millis() + 10000;
  if (vehicleCharging && lastUsername.compareTo("vehicle") != 0) {
    return;
  } 

  int daynow = weekday(ntp.getUtcTimeNow()) + 48;

  time_t timenow = 0;
  timenow += hour(ntp.getUtcTimeNow()) * 3600;
  timenow += minute(ntp.getUtcTimeNow()) * 60;
  timenow += second(ntp.getUtcTimeNow());

  File timerFile = SPIFFS.open("/timer.json", "r");
  if (!timerFile) {
    millisCheckTimer = millis() + 10000;
    if(config.getSystemDebug()) slog.logln(ntp.iso8601DateTime() + "[ ERR ] Timer File does not exist");
    return;
  }
  size_t size = timerFile.size();
  std::unique_ptr<char[]> buf(new char[size]);
  timerFile.readBytes(buf.get(), size);
  DynamicJsonDocument jsonDoc(1800);
  DeserializationError error = deserializeJson(jsonDoc, buf.get());
  timerFile.close();
  if (error) {
    millisCheckTimer = millis() + 10000;
    if(config.getSystemDebug()) slog.logln(ntp.iso8601DateTime() + "[ ERR ] Timer File does not exist");
    return;
  }

  //Check global timer Settings
  bool timerGlobalActive;
  if (jsonDoc.containsKey("active")) {
    timerGlobalActive = jsonDoc["active"];
  }
  else {
    timerGlobalActive = true;
  }
  bool minOneTimerActive = false;

  //Loop through timer objects
  JsonArray timerArray = jsonDoc["list"];
  bool timerToActivate = false;
  bool timerToDeactivate = false;
  uint16_t timerCurrentToSet = 0;
  for (size_t i = 0; i < timerArray.size(); i++) {
    JsonObject tObj = timerArray[i];
    if (tObj["active"] == true) { //timer is globally active
      minOneTimerActive = true;
      time_t from = tObj["from"];
      time_t to = tObj["to"];
      const char* days = tObj["days"];

      // Activate Timer
      if (timenow >= from && timenow <= to && strrchr(days, daynow) != NULL){
        timerCurrentToSet = tObj["current"];
        timerToActivate = true;
        break;
      }
      // No Timer match
      else {
          timerToDeactivate = true;
      }
    }
  }
  if (!config.getEvseAlwaysActive(0) && timerToActivate && timerGlobalActive){
    if (timerActive == false) {
      timerActivateMatch(timerCurrentToSet);
    } /*
    else if (timerCurrentToSet != evseAmpsConfig) {
      currentToSet = timerCurrentToSet;
      setEVSEcurrent();
    } */
    return;
  }
  if ((!config.getEvseAlwaysActive(0) && timerToDeactivate && timerActive == true && timerGlobalActive) ||  // Timer run out or
      (!config.getEvseAlwaysActive(0) && !minOneTimerActive && timerActive == true) ||                      // No Timer value is active but timerActive == true
      (!config.getEvseAlwaysActive(0) && timerGlobalActive == false && timerActive == true)) {              // Timer globally deactivated but timerActive == true
    timerDeactivateMatch();
  }
}

void ICACHE_FLASH_ATTR timerActivateMatch(uint16_t current) {
  if (setEVSERegister(2005, reg2005DefaultValues)){
    addEvseData.evseReg2005 = reg2005DefaultValues;
    timerActive = true;
  }
  if (current != 0) {
    delay(150);
    toSetEVSEcurrent = true;
    currentToSet = current;
  }
}
void ICACHE_FLASH_ATTR timerDeactivateMatch() {
  if (vehicleCharging) deactivateEVSE(true);
  if (setEVSERegister(2005, reg2005DefaultValues + 16384)) {
    addEvseData.evseReg2005 = reg2005DefaultValues + 16384;
    timerActive = false;
  }
}


void ICACHE_FLASH_ATTR turnOnOled(uint32_t ontimesecs = config.getSystemOledOnTime()) {
  #ifdef ESP32
  millisOnTimeOled = millis() + ontimesecs * 1000; 
  oled.turnOn();
  //if(config.getSystemDebug()) slog.logln(ntp.iso8601DateTime() + "[ oLED ] Display turned on");
  #endif
}

#ifndef ESP8266
void ICACHE_FLASH_ATTR handleRse() {
  if (rseActive) { //RSE goes activated
    toSetEVSEcurrent = true;
    currentBeforeRse = evseAmpsConfig;
    currentToSet = int(float(evseAmpsConfig) / 100.0 * float(config.getEvseRseValue(0)));
    if (currentToSet > 0 && currentToSet < 6) currentToSet = 6;
    if (config.getEvseRseValue(0) == 0) currentToSet = 0;
    sliderStatus = false;
    if(config.getSystemDebug()) slog.log(ntp.iso8601DateTime() + "[ SYSTEM ] RSE Interrupted! Setting current to ");
    if(config.getSystemDebug()) slog.logln(currentToSet);
  }
  else { //RSE goes deactivated
    toSetEVSEcurrent = true;
    currentToSet = currentBeforeRse;
    if (!config.getEvseRemote(0)) sliderStatus = true;
    if(config.getSystemDebug()) slog.log(ntp.iso8601DateTime() + "[ SYSTEM ] RSE Released! Setting current back to ");
    if(config.getSystemDebug()) slog.logln(currentToSet);
  }
}
#endif

uint16_t get16bitOfFloat32 (float float_number, uint8_t offset){
  union {
    float f_number;
    uint16_t uint16_arr[2];
  } union_for_conv;  
  union_for_conv.f_number = float_number;
  uint16_t ret = union_for_conv.uint16_arr[offset];
  return ret;
}

void ICACHE_FLASH_ATTR handleLed() {
  if (showLedRfidGrant && millis() < millisRfidLedAction) {
    digitalWrite(config.getEvseLedPin(0), HIGH);
    return;
  }
  else if (showLedRfidGrant && millis() >= millisRfidLedAction) {
    showLedRfidGrant = false;
    digitalWrite(config.getEvseLedPin(0), LOW);
    return;
  }
  else if (showLedRfidDecline && millis() >= millisRfidLedAction) {
    showLedRfidDecline = false;
    changeLedTimes(100, 10000);
    return;
  }

  if (currentMillis >= previousLedAction && config.getEvseLedConfig(0) != 1) {
    if (ledStatus == false) {
      if (currentMillis >= previousLedAction + ledOffTime) {
        digitalWrite(config.getEvseLedPin(0), HIGH);
        ledStatus = true;
        previousLedAction = currentMillis;
      }
    }
    else {
      if (currentMillis >= previousLedAction + ledOnTime) {
        digitalWrite(config.getEvseLedPin(0), LOW);
        ledStatus = false;
        previousLedAction = currentMillis;
      }
    }
  }
}

void ICACHE_FLASH_ATTR changeLedStatus() {
  if (ledOnTime != toChangeLedOnTime) {
    ledOnTime = toChangeLedOnTime;
  }
  if (ledOffTime != toChangeLedOffTime) {
    ledOffTime = toChangeLedOffTime;
  }
}

void ICACHE_FLASH_ATTR changeLedTimes(uint16_t onTime, uint16_t offTime) {
  if (ledOnTime != onTime) {
    toChangeLedOnTime = onTime;
  }
  if (ledOffTime != offTime) {
    toChangeLedOffTime = offTime;
  }
}

String ICACHE_FLASH_ATTR printIP(IPAddress address) {
  return (String)address[0] + "." + (String)address[1] + "." + (String)address[2] + "." + (String)address[3];
}

bool ICACHE_FLASH_ATTR setSmartWb11kWSettings() {
  //Load and Save config file for smartWB
  if (config.saveConfigFile(SRC_CONFIG_TEMPLATE_SMARTWB11KW)) {
    slog.logln(ntp.iso8601DateTime() + "[ Auto-Config ] config.json for smartWB 11kW successfully loaded and saved");
  }
  else {
    slog.logln(ntp.iso8601DateTime() + "[ Auto-Config ] [ !!! ] Error while loading config.json for smartWB 11kW!");
  }

  bool err = false;
// Setting SDM Meter ID
  delay(200);
  for (size_t i = 0; i < 3; i++) {
    if (setSDMID() == false) {
      delay(200);
      err = true;
      slog.logln(ntp.iso8601DateTime() + "[ Auto-Config ] [ !!! ] Error while setting SDM ID to 2");
    }
    else {
      slog.logln(ntp.iso8601DateTime() + "[ Auto-Config ] SDM ID successfully set to 2");
      err = false;
      break;
    }
  }

// Setting EVSE Registers for smartWB 11kW
  delay(200);
  for (size_t i = 0; i < 3; i++) {
    if (setEVSERegister(2000, 16) == false) {
      delay(200);
      err = true;
      slog.logln(ntp.iso8601DateTime() + "[ Auto-Config ] [ !!! ] Error while setting register 2000");
    }
    else {
      slog.logln(ntp.iso8601DateTime() + "[ Auto-Config ] Register 2000 successfully set");
      err = false;
      break;
    }
  }
  delay(200);
  for (size_t i = 0; i < 3; i++) {
    if (setEVSERegister(2002, 6) == false) {
      delay(200);
      err = true;
      slog.logln(ntp.iso8601DateTime() + "[ Auto-Config ] [ !!! ] Error while setting register 2002");
    }
    else {
      slog.logln(ntp.iso8601DateTime() + "[ Auto-Config ] Register 2002 successfully set");
      err = false;
      break;
    }
  }
  delay(200);
  for (size_t i = 0; i < 3; i++) {
    if (setEVSERegister(2004, 0) == false) {
      delay(200);
      err = true;
      slog.logln(ntp.iso8601DateTime() + "[ Auto-Config ] [ !!! ] Error while setting register 2004");
    }
    else {
      slog.logln(ntp.iso8601DateTime() + "[ Auto-Config ] Register 2004 successfully set");
      err = false;
      break;
    }
  }
  delay(200);
  for (size_t i = 0; i < 3; i++) {
    if (setEVSERegister(2007, 16) == false) {
      delay(200);
      err = true;
      slog.logln(ntp.iso8601DateTime() + "[ Auto-Config ] [ !!! ] Error while setting register 2007");
    }
    else {
      slog.logln(ntp.iso8601DateTime() + "[ Auto-Config ] Register 2007 successfully set");
      err = false;
      break;
    }
  }

  slog.logln(ntp.iso8601DateTime() + "[ Auto-Config ] Going to interrupt CP for 500ms");
  digitalWrite(config.getEvseCpIntPin(0), HIGH);
  delay(500);
  digitalWrite(config.getEvseCpIntPin(0), LOW);
  slog.logln(ntp.iso8601DateTime() + "[ Auto-Config ] CP interrupt ended - going to Reboot now...");

  toReboot = true;
  if (err){
    slog.logln(ntp.iso8601DateTime() + "[ !!! ] Error occured while setting settings and/or EVSE registers for smartWB 11kW (see error message/s)");
    return false;
  }
  else {
    slog.logln(ntp.iso8601DateTime() + "[ Auto-Config ] Settings and EVSE registers for smartWB 11kW successfully set");
    return true;
  }
}

#ifndef ESP8266
String ICACHE_FLASH_ATTR printSubnet(uint8_t mask) {
  String ret = "";
  while (mask >= 8) {
    if (mask >= 8) {
      ret += "255.";
      mask -= 8;
    }
  }
  if (mask == 0) {
    ret += "0";
  }
  else {
    int lastOct = 8 * mask;
    ret += (String)lastOct;
  }
  if (ret.substring(ret.length() - 1) == ".") ret.remove(ret.length() - 1);
  return ret;
}
#endif

void ICACHE_FLASH_ATTR parseBytes(const char* str, char sep, byte* bytes, int maxBytes, int base) {
  for (int i = 0; i < maxBytes; i++) {
    bytes[i] = strtoul(str, NULL, base);
    str = strchr(str, sep);
    if (str == NULL || *str == '\0') {
      break;
    }
    str++;
  }
}

void ICACHE_RAM_ATTR handleMeterInt() {  //interrupt routine for metering
  if (meterImpMillis < millis()) {
    meterImpMillis = millis() + (config.getMeterImpLen(0) + 10);
    meterInterrupt ++;
    numberOfMeterImps ++;
  }
}

void ICACHE_FLASH_ATTR updateS0MeterData() {
  if (vehicleCharging) {
    currentKW = 3600.0 / float(meterImpMillis - previousMeterMillis) / float(config.getMeterImpKwh(0) / 1000.0) * (float)config.getMeterFactor(0) ;  //Calculating kW
    previousMeterMillis = meterImpMillis;
    meteredKWh = float(numberOfMeterImps) / float(config.getMeterImpKwh(0) / 1000.0) / 1000.0 * float(config.getMeterFactor(0));
  }
  meterInterrupt = 0;
}

void ICACHE_FLASH_ATTR updateMMeterData() {
  float fRes = 0.0;
  if (config.mMeterTypeSDM120 == true) {
    fRes = readMeter(0x000C);
    if (fRes >= 0.0) {
      currentKW = fRes / 1000.0;
    }
    fRes = readMeter(0x0156);
    if (fRes >= 0.0) {
      meterReading = fRes;    
    }
  }
  else if (config.mMeterTypeSDM630 == true) {
    fRes = readMeter(0x0034);
    if (fRes >= 0.0) {
      currentKW = fRes / 1000.0;
    }
    fRes = readMeter(0x0156);
    if (fRes >= 0.0) {
      meterReading = fRes;    
    }
  }
  if (meterReading != 0.0 &&
      vehicleCharging == true) {
    meteredKWh = meterReading - startTotal;
  }
  if (startTotal == 0) {
    meteredKWh = 0.0;
  }
  updateSDMMeterCurrent();
  millisUpdateMMeter = millis() + 5000;
}

void ICACHE_FLASH_ATTR updateSDMMeterCurrent() {
  if (noSDM) {
    slog.logln(ntp.iso8601DateTime() + "[ ERR ] No SDM meter detected!");
    return;
  }
  const int regsToRead = 12;
  uint8_t result;
  uint16_t iaRes[regsToRead];
  meterNode.clearTransmitBuffer();
  meterNode.clearResponseBuffer();
  delay(50);
  result = meterNode.readInputRegisters(0x0000, regsToRead); // read 6 registers starting at 0x0000

  if (result != 0) {
    slog.log(ntp.iso8601DateTime() + "[ ModBus ] Error ");
    slog.log(result, true);
    slog.logln(" occured while getting current Meter Data");
    if (config.getEvseLedConfig(0) == 3) changeLedTimes(300, 300);
    return;
  }

  for (int i = 0; i < regsToRead; i++) {
    iaRes[i] = meterNode.getResponseBuffer(i);
  }
  ((uint16_t*)&voltageP1)[1]= iaRes[0];
  ((uint16_t*)&voltageP1)[0]= iaRes[1];
  ((uint16_t*)&voltageP2)[1]= iaRes[2];
  ((uint16_t*)&voltageP2)[0]= iaRes[3];
  ((uint16_t*)&voltageP3)[1]= iaRes[4];
  ((uint16_t*)&voltageP3)[0]= iaRes[5];

  ((uint16_t*)&currentP1)[1]= iaRes[6];
  ((uint16_t*)&currentP1)[0]= iaRes[7];
  ((uint16_t*)&currentP2)[1]= iaRes[8];
  ((uint16_t*)&currentP2)[0]= iaRes[9];
  ((uint16_t*)&currentP3)[1]= iaRes[10];
  ((uint16_t*)&currentP3)[0]= iaRes[11];
}

unsigned long ICACHE_FLASH_ATTR getChargingTime() {
  unsigned long iTime;
  if (vehicleCharging == true) {
    //iTime = millis() - millisStartCharging;
    iTime = (ntp.getUtcTimeNow() - startChargingTimestamp) * 1000;

  }
  else {
    //iTime = millisStopCharging - millisStartCharging;
    iTime = (stopChargingTimestamp - startChargingTimestamp) * 1000;
  }
  return iTime;
}

bool ICACHE_FLASH_ATTR resetUserData() {
  #ifdef ESP8266
  Dir userdir = SPIFFS.openDir("/P/");
  while(userdir.next()){
    slog.logln(userdir.fileName());
    SPIFFS.remove(userdir.fileName());
  }
  #else
  File userdir = SPIFFS.open("/P/");
  while(userdir.openNextFile()){
    slog.logln(userdir.name());
    SPIFFS.remove(userdir.name());
  }
  #endif
  delay(10);
  return true;
}

bool ICACHE_FLASH_ATTR factoryReset() {
  if(config.getSystemDebug()) slog.logln(ntp.iso8601DateTime() + "[ SYSTEM ] Factory Reset...");
  SPIFFS.remove("/config.json");
  initLogFile();
  if (resetUserData()) {
    if(config.getSystemDebug()) slog.logln(ntp.iso8601DateTime() + "[ SYSTEM ] ...successfully done - going to reboot");
  }
  toReboot = true;
  delay(100);
  return true;
}
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

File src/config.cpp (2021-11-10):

#include "config.h"
#include "templates.h"
#include <string.h>

bool ICACHE_FLASH_ATTR EvseWiFiConfig::loadConfig(String givenConfig) {
    String jsonString;
    bool loadDefault = false;
    configLoaded = false;
    pre_0_4_Config = false;
    
    if (givenConfig != "") {
        Serial.println("loadConfig: given config string...");
        jsonString = givenConfig;
    }
    else {
        //SPIFFS.begin();
        Serial.println("loadConfig: no config string given -> check config file");
        File configFile = SPIFFS.open("/config.json", "r");
        #ifdef ESP8266
        if (!configFile) {
            Serial.println("loading config file failed");
            return false;
        }
        #else
        if (!configFile.available()) {
            configFile.close();
            Serial.println("loading config file failed - rebuild factory settings");
            loadDefault = true;
        }
        #endif
        if (loadDefault) {
            jsonString = SRC_CONFIG_TEMPLATE;
        }
        else {
            while (configFile.available()) {
                jsonString += char(configFile.read());
            }
        }
        //SPIFFS.end();
    }

    DynamicJsonDocument jsonDoc(2000);
    DeserializationError error = deserializeJson(jsonDoc, jsonString);
    if (error) {
        Serial.println("parsing config file failed");
        return false;
    }
    
    if (!jsonDoc.containsKey("configversion")) {
        pre_0_4_Config = true;
        Serial.println("pre 0.4 config file found...");
    }
    else {
        Serial.println("actual config file found");
    }

    // wifiConfig
    wifiConfig.bssid = strdup(jsonDoc["wifi"]["bssid"]);
    wifiConfig.ssid = strdup(jsonDoc["wifi"]["ssid"]);
    wifiConfig.wmode = jsonDoc["wifi"]["wmode"];
    wifiConfig.pswd = strdup(jsonDoc["wifi"]["pswd"]);
    wifiConfig.staticip = jsonDoc["wifi"]["staticip"];
    wifiConfig.ip = strdup(jsonDoc["wifi"]["ip"]);
    wifiConfig.subnet = strdup(jsonDoc["wifi"]["subnet"]);
    wifiConfig.gateway = strdup(jsonDoc["wifi"]["gateway"]);
    wifiConfig.dns = strdup(jsonDoc["wifi"]["dns"]);
    Serial.println("WIFI loaded");

    // meterConfig
    meterConfig[0].usemeter = jsonDoc["meter"][0]["usemeter"];
    meterConfig[0].metertype = strdup(jsonDoc["meter"][0]["metertype"]);
    meterConfig[0].price = jsonDoc["meter"][0]["price"];
    meterConfig[0].intpin = jsonDoc["meter"][0]["intpin"];
    meterConfig[0].kwhimp = jsonDoc["meter"][0]["kwhimp"];
    meterConfig[0].implen = jsonDoc["meter"][0]["implen"];
    meterConfig[0].meterphase = jsonDoc["meter"][0]["meterphase"];
    meterConfig[0].factor = jsonDoc["meter"][0]["factor"];
    Serial.println("METER loaded");

    // rfidConfig
    rfidConfig.userfid = jsonDoc["rfid"]["userfid"];
    rfidConfig.sspin = jsonDoc["rfid"]["sspin"];
    rfidConfig.rfidgain = jsonDoc["rfid"]["rfidgain"];
    Serial.println("RFID loaded");

    // ntpConfig
    ntpConfig.timezone = jsonDoc["ntp"]["timezone"];
    ntpConfig.ntpip = strdup(jsonDoc["ntp"]["ntpip"]);
    Serial.println("NTP loaded");
    if (jsonDoc["ntp"].containsKey("dst")) {
        ntpConfig.dst = jsonDoc["ntp"]["dst"];
    }
    else {
        ntpConfig.dst = false;
    }

    // buttonConfig
    buttonConfig[0].usebutton = jsonDoc["button"][0]["usebutton"];
    buttonConfig[0].buttonpin = jsonDoc["button"][0]["buttonpin"];
    Serial.println("BUTTON loaded");

    // systemConfig
    systemConfig.hostnm = strdup(jsonDoc["system"]["hostnm"]);
    if (jsonDoc["system"].containsKey("language")) {
        systemConfig.language = strdup(jsonDoc["system"]["language"]);
    }
    else {
        systemConfig.language = "en";
    }
    systemConfig.adminpwd = strdup(jsonDoc["system"]["adminpwd"]);
    systemConfig.wsauth = jsonDoc["system"]["wsauth"];
    systemConfig.debug = jsonDoc["system"]["debug"];
    systemConfig.maxinstall = jsonDoc["system"]["maxinstall"];
    systemConfig.evsecount = jsonDoc["system"]["evsecount"];
    systemConfig.configversion = jsonDoc["configversion"];
    if (jsonDoc["system"].containsKey("logging")) {
        systemConfig.logging = jsonDoc["system"]["logging"];
    }
    else {
        systemConfig.logging = true;
    }
    if (jsonDoc["system"].containsKey("api")) {
        systemConfig.api = jsonDoc["system"]["api"];
    }
    else {
        systemConfig.api = true;
    }
    if (jsonDoc["system"].containsKey("oledontime")) {
        systemConfig.oledontime = jsonDoc["system"]["oledontime"];
    }
    else {
        systemConfig.oledontime = 120;
    }
    Serial.println("SYSTEM loaded");

   // evseConfig
    evseConfig[0].mbid = 1;
    evseConfig[0].alwaysactive = jsonDoc["evse"][0]["alwaysactive"];

    evseConfig[0].resetcurrentaftercharge = jsonDoc["evse"][0]["resetcurrentaftercharge"];
    evseConfig[0].maxcurrent =  jsonDoc["evse"][0]["maxinstall"];
    evseConfig[0].avgconsumption = jsonDoc["evse"][0]["avgconsumption"];
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

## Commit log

2018-04-16 update to 0.1.1
    added
    - default hostname
    changed
    - navbar
    - tidy up code
    - wifi protection when configured ap is not reachable
    - autorestart interval hard coded to 7 days
    - update log and disable evse before rebooting, when vehicle is charging (reduces incomplete log entries)
    - update log on boot, if power supply get lost while charging (reduces incomplete log entries)
    - some small things
    [SimpleEVSE-WiFi.ino]
2018-04-28 Update to 0.2.0
    - API to control SimpleEVSE WiFi via another webbased device (see API documentation)
    - all modbus registers are availible in settings page now
    buxfixes
    - WiFi bug in AP mode solved
    - solved "activate loop" when evse already active
    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
    [SimpleEVSE-WiFi.ino]
2018-04-30 bugfix NTP update
    fixed problem with NTP update in client mode
    [SimpleEVSE-WiFi.ino]
2018-05-04 Insert link to ESP 8266 Core
    As SoftwareSerial and WiFi need the latest Version of ESP8266 Core I have mentioned it one more time
2018-05-09 update to 0.2.1
    [*] improvement GUI - GUI is now stored in sketch instead of SPIFFS
    [*] improvement GUI - single HTML and JS File
    [*] improvement GUI - all GUI files are now compressed
    [*] bugfix NTP - fixed timeout when no internet connection is availible in client mode
    [SimpleEVSE-WiFi.ino]
2018-05-22 update to v0.2.2
    improvements
    - bugfix - reboot every 15-20 minutes
    - changed Ping-Library
    - GUI - validate more data on settings page
    - GUI - improve auto-fill BSSID
    - GUI - correct progress bar "available flash"
    - upgrade to Arduino ESP8266 v2.4.1
    - factor for meter settings (e.g. if you use a 1-phase meter and your car charges with 3 phases)
    - average consumtion for calculating charged mileage
    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
    [SimpleEVSE-WiFi.ino]
2018-05-29 update to v0.2.3
    - manual control of EVSE modbus registers via GUI
    - redesign fallback mode (now Simple EVSE-WiFi will reboot every 10 minutes when you are in fallback mode)
    - changed glyphicon for "charged mileage"
    - EVSE WB will be deactivated if button is pushed and evse is already active
    - more stable fallback mode
    - GUI - some small bugfixes
    - bugfix - meter with imp/kwh < 1000 is now supported
    - bugfix - activating via button and deactivating via GUI occured in re-activating (now use GPIO-2 for button because of missing internal pullup on GPIO-16)
    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
    [SimpleEVSE-WiFi.ino]
2018-06-03 update to 0.2.3-patch1
    bugfix - activate/deactivate via button
    [SimpleEVSE-WiFi.ino]
2018-06-26 update to v0.2.4
    - support static ip address
    - add support RS485 meter (e.g. SDM series) - experimental!
    - firmware version in sidebar
    - API integration: charged mileage
    - give two decimals for "power"
    - give one decimal for "mileage"
    - manual change of impulse lenght of S0 meter
    - delete selection of GPIO-16 for S0 and button
    - update EVSE Control every 3s instead of 1s ->reduce traffic
    improvement
    - some more checks of config file
    - reduce time of wifi connect in client mode
    - improve accuracy of measured power and energy (S0)
    bugfix
    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
    [SimpleEVSE-WiFi.ino]
2018-06-28 update to 0.2.4-patch1
    API now returns correct float values
    [SimpleEVSE-WiFi.ino]
2018-07-21 update to 0.2.5
    - API extenstion for openWB
    - experimental support for SDM630
    - output amount of charging costs to EVSE Control
    - manual configuration of NTP server
    - added debug mode (to keep Serial silent - modbus meter goes more stable)
    - new input field to define S0 meter (1p/3p)
    changed:
    - deactivate EVSE via RFID tag
    - output error message when activating EVSE via API while EVSE is already activated
    - input field "factor" moved to "car" section
    bugfix/improvements
    - NTP support more stable
    - faster reboot after saving settings
    - bugfix in "updateLog" (wrong rounding of "energy" parameter)
    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
    [SimpleEVSE-WiFi.ino]
2018-10-14 update to 0.2.6
    - "Reset Log File" function
    - animation while uploading firmware file (firmware update)
    - some code cleanup
    - print some errors and the configured ip address to serial when debug mode is NOT active
    - default login passwort changed to "adminadmin" (min 8 characters)
    bugfixes/improvements
    - improved websocket (more stable)
    - improved modbus meter (more stable)
    - metered energy is not aggregated correctly (modbus meter only)
    - save and reboot work now (issue when using S0 meter AND static IP address)
    - heap leak when using the API
    - restore user backup works now
    library updates
    - ESP8266 Core 2.4.1 -> 2.4.2
    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
    [SimpleEVSE-WiFi.ino]
2018-10-17 0.2.6-patch1
    - update log when deactivate via API
    - reset "Power" at EVSE Control when charging stops
    [SimpleEVSE-WiFi.ino]
2018-12-27 update to 0.2.7
    - possibility to deactivate basicAuth (Safari Mode) in Settings to fix Problem with Safari Browser
    - fixed meter reading via API
    [SimpleEVSE-WiFi.ino]
2019-11-04 Support PlatformIO and add ESP32 platform (#29)
    * Add support for PlatformIO
    * Ignore .vscode
2019-11-22 update to 0.2.8
    - API: when activating/deactivating via API the response of getParameters is now correct
    - refereces to evse-wifi.de
    - ArduinJson 5.13.2 -> 5.13.5
    - MFRC 1.4.0 -> 1.4.5
    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
    [SimpleEVSE-WiFi.ino]
2019-12-03 update to 0.3.0
    - Added "Always Active mode". When activating it:
    - Activating/Deactivating EVSE is not possible ("setStatus" via API has no effect anymore)
    - Register 2005 is set to 0
    - "evseStatus" is always "true"
    - API: Added Parameter "maxCurrent" to "getParameters"
    - API: Reboot EVSE-WiFi with "/doReboot?reboot=true"
    - double enter admin password when changing it
    - reboot EVSE-WiFi, when button is pressed for 10 seconds
    - possibility to reset the current value to "Default amps value after boot" (EVSE Register 2000) after charging.
    - allow setting current to 5 (API only)
    - UI: Slider maximum depends now on "Max Current" (settings page) and PP limit
    bugfixes
    - UI: S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
    [SimpleEVSE-WiFi.ino]
2019-12-22 update to 0.3.1
    - LED Support for Pin D0 (GPIO16)
    - API: new Items in "/getParameters"
    - "alwaysActive" - to detect always active mode
    - "lastActionUser" - The user name of the user who performed the last action (activate/deactivate)
    - "lastActionUID" - The UID of the user who performed the last action (activate/deactivate)
    - API: support for setting current to 0 in always active mode
    - API: added value 5 to vehicleState in "getParameters" (failure)
    - API: giving Uptime in "/evseHost"
    - auto reboot ESP after 45 days when no vehicle is charging (to prevent millis-overflow)
    - Button in always active mode is now disabled (except reboot functionality)
    - A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
    [SimpleEVSE-WiFi.ino]
2019-12-22 bugfix API
    set lastActionUser and lastActionUID also when deactivating via WebUI
    [SimpleEVSE-WiFi.ino]
2020-03-15 update to 0.4.1
    new
    - System: changed IDE to PlatformIO
    - Config: New config layout with automated migration of pre-0.4.0-config files
    - GUI: Show WiFi signal strength in "additional information“
    - System: Added "Factory Reset“
    - GUI: new button "Factory Reset“ at settings page
    - Button: when button pressed for about 30 sec settings will be set to default (after 10 sec the LED switchs on, after 20 additional sec LED switches off – Factory Reset successfull)
    - GUI: Userdata Reset deletes all RFID users (Settings Page - "Userdata Reset“)
    - System: Modbus timeout changed from 500ms to 250ms. That offers a better system stability, especially when there is no EVSE WB/DIN con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
    [config.cpp, main.cpp, rfid.cpp]
2020-07-26 update to 1.0.1 and 2.0.1 (ESP32)
    - added ESP32 Support
    - GUI: Shows PP-Limit in EVSE Control if PP-Limit < Max current
    - GUI: Displays more Modbus Registers of SDM-Meters
    - New Operating Mode: 'Remote Controlled' - User cannot make aby changes via EVSE Control
    - added support for Daylight Saving Time
    - ESP32-only:
    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
2020-08-02 Dev update to x.0.2 (#56)
    * Update platformio.ini
    * update x.0.2
    bugfix:
    - reset current after charge can now be saved in settings
    - reducing the risk of corrupt files when saving the log file
    * Update README.md
    * moved bin files
    moved bin files to www.evse-wifil.de/download
    [main.cpp]
2020-11-20 Dev Update to 1.0.4 (#59)
    * v1.0.4
    new:
    - display rotation possible (esp32 only) 0°, 90°, 180°, 270°
    - implementation of Modbus/TCP to control EVSE-WiFi externally
    - new API parameter 'useMeter' to indicate that an energy meter is used
    - EVSE modbus registers > 2002 are no longer editable
    - switched to hw serial instead of sw serial (esp32 only)
    - keep the charging data (GUI and oLED) until a new charg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
    [config.cpp, main.cpp, oled.h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]
2020-11-20 Dev Update Readme (#60)
    - keep the charging data (GUI and oLED) until a new chargin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
2021-01-06 v1.0.6 (#63)
    - keep the charging data (GUI and oLED) until a new charging process s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
    [config.cpp, main.cpp]
2021-01-23 push to vX.1.0
    - updated oLED Output
    - added favicon
    - separate Status Page in GUI
    - bugfixes
    [main.cpp, oled.h, oled_templates.h]
2021-07-09 update to 2.2.4-beta2
    -System stability improvements for remote mode
    -some API extenstions
    [main.cpp]
2021-11-10 v2.3.0
    Added
    - german translation
    - systemlog
    - RFID support for openWB/EVCC
    Changed:
    - show IP at startup (oled)
    - bug fixes
    [config.cpp, main.cpp, oled.h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]
